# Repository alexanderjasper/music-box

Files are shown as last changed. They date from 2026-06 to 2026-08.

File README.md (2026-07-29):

# Music Box

A phone-free way to control our Sonos speakers at home.

Place a physical card on the device, press play, and a corresponding album,
playlist, or radio station starts playing on one or more speakers. No screen to
get lost in, no app to open — just a tactile object and a button.

> **Status:** Scoping / idea phase. This README is a living design document.
> Nothing is built yet. Decisions marked **(open)** are still to be made.

---

## Motivation

When I'm home, I want to fully put my phone away. Today, playing music on our
3 Sonos speakers requires picking music or a radio station through the Sonos
app on my phone every single time. That pulls the phone back into my hand — and
my attention with it.

The Music Box replaces that with a physical, ambient interaction:

- Pick a card (album / playlist / radio station / mood).
- Place it on the box.
- Press play.
- Music plays on the speaker(s).

The phone stays away.

---

## Core concept

```
   [ physical card ]                  [ Sonos speakers ]
          │                                   ▲
          ▼                                   │
   ┌──────────────┐     local network /       │
   │  Music Box   │ ───── UPnP / API ─────────┘
   │  (no display)│
   │  buttons +   │
   │  card reader │
   └──────────────┘
          ▲
          │ configuration over Wi-Fi / Bluetooth
          │ (map card → music, no display needed on device)
   [ phone / laptop, only for setup ]
```

The phone is still allowed for **one-time configuration** (mapping a card to a
playlist). The goal is zero phone use for **everyday playback**.

---

## Goals

- **No general-purpose display.** Buttons only. Optionally a minimal display for
  track progress / time elapsed / volume — nothing you'd "browse".
- **Tactile cards** to select what plays.
- **One or more speakers** targetable per action (grouping).
- **Configuration off-device** — over local network and/or Bluetooth, from a
  phone or laptop.
- **Built from off-the-shelf electronics + 3D-printed enclosure** (Prusa Core One).
- Reliable and fast enough that it actually replaces the app for daily use.

## Non-goals (for now)

- Not trying to replicate the full Sonos app.
- No on-device music browsing/search.
- No cloud service of our own — keep everything local where possible.

---

## Open questions to scope together

These are the big decisions. We'll work through them and record the outcomes here.

### 1. Card technology **(DECIDED: NFC)**
**NFC tags** — an NTAG215 sticker hidden inside each 3D-printed card, read by a
PN532/RC522 reader in the box. Cheap (~€0.20/card), batteryless, scales to 100s,
solder-free modules exist. The card just rests on a marked "spot." Each tag's UID
(or a written ID) maps to a Sonos Favorite in the box config.

### 2. The "brain" **(leaning Raspberry Pi — see findings)**
What runs the logic and talks to Sonos?
- **Raspberry Pi Zero 2 W** — runs Linux + Python, uses [SoCo] directly, hosts the
  config web app easily. The findings make this the strong default: SoCo is the
  proven, maintained path and needs a real OS. Boots slower / more power than an MCU,
  but for an always-on box that's fine.
- **ESP32** — cheap, instant-on, but would need raw UPnP reimplemented (no SoCo) and
  the config web app is more work. Findings push this *down* the list.
- Other (Pi 4/5, etc.) — overkill but flexible.

[SoCo]: https://github.com/SoCo/SoCo

### 3. How we talk to Sonos **(open)**
- **Local UPnP control** (SoCo) — no internet dependency, works on the LAN.
- Sonos **favorites** as the unit of selection — easiest mapping target: a card
  → a Sonos favorite (which can be an album, playlist, or radio station).
- Music sources we care about (**decided**, see findings below): **Apple Music**,
  **DR radio + DR podcasts** (via the **DR LYD** Sonos service). Other services
  can be added later. Podcasts beyond DR are a known gap — see findings.

### 4. Buttons & controls **(DECIDED — see "Control scheme" below)**
Settled on, per room: a **latching push-button** (arm/disarm, room label on the cap,
stays pressed in when armed — no LED) **and** a separate **volume knob** (rotary
encoder). Plus **shuffle** + **repeat** latching symbol buttons, **previous / play /
next** momentary buttons, and a **piezo buzzer** for audio feedback. No LEDs anywhere
on the box. No dedicated mute (disarm a room, or turn its knob to zero).

### 5. Display: none vs. minimal **(open)**
- None at all.
- Minimal: small OLED / e-ink showing track name + elapsed/remaining time +
  volume. Nice-to-have, not required for v1.

### 6. Configuration interface **(DECIDED: LAN web app with live card enrollment)**
A small **web app served by the box** on the LAN, opened from any phone/laptop. On the
finished Pi this is reachable at **`musicbox.local`** (Raspberry Pi OS ships Avahi/mDNS,
so setting the Pi's hostname to `musicbox` makes `<hostname>.local` resolve with no DNS
setup; the bare name needs the app on port 80, otherwise it's `musicbox.local:8080`). On
the **dev machine today** it's `http://localhost:8080` (and `http://<LAN-IP>:8080` from a
phone) — the simulator doesn't advertise the `musicbox` name. It lists your **Sonos
Favorites live** (via SoCo) and lets you bind a card
by simply **placing it on the box's own NFC spot** — the PN532 reads the UID and the page
captures it. See "Card configuration" below for the full flow. No Bluetooth flow for v1.

### 7. Card ↔ action model **(DECIDED: card = a named Sonos Favorite, content only)**
A card stores **just the favorite** (its NFC UID → favorite name in the box config).
**Rooms and volume are chosen live** with the panel buttons/knobs each time, not baked
into the card — so cards stay interchangeable. (Considered and deferred: "scene" cards
that also remember rooms/mode/volume. The data model leaves room to add optional defaults
later without breaking existing cards.)

### 8. Power & resilience **(DECIDED: wall power for v1; read-only root FS; battery deferred — two options documented)**

**v1 is wall-powered** — a **5V micro-USB PSU (≥2.5A)** (the Pi Zero takes micro-USB, *not*
USB-C). For an always-on box that drives Sonos, mains is the simplest, most reliable choice
and a battery buys nothing for everyday use.

**Read-only root filesystem — decided regardless of power source.** The box runs with
Raspberry Pi OS's **overlay filesystem** (`raspi-config` → Performance → Overlay FS): root
mounts read-only with a RAM overlay, so **any power cut — yanked cable, home outage, or a
drained battery — can never catch the SD card mid-write.** This removes the real risk of
ungraceful shutdown, which is *not* our app's data (just `cards.json`, written rarely during
enrollment) but **OS/SD corruption** from background writes + the SD card's own wear-levelling
— a risk independent of how little we write. `cards.json` lives on a small writable partition
and is saved **atomically** (temp file → `fsync` → rename), so a yank yields either the old or
new file, never a torn one. This hardens the *wall-powered* box too (outages, "unplug = done").

**Battery is deferred — an optional "portability" mode, not in v1.** v1 ships wall-powered;
the goal *if* battery is added later is to actually carry the box between rooms / outside. Two
options are documented (full parts in the BOM "Battery / portability" section); pick when/if
the time comes. Either way the **read-only root FS** above means a flat pack or yanked cable
can't corrupt the SD card.

- **Option A — rechargeable AA (NiMH).** No lithium in a printed case, cells **hot-swap** (keep
  a charged spare set), core parts all at BerryBase. **4× AA + a 5V buck-boost** → the Pi's 5V;
  ~4× 2000mAh ≈ 9.6Wh → roughly **8 h** at the box's ~1W draw. Trade-offs: recharge by *swapping*
  cells (NiMH needs an external charger — no charge-in-place), and no fuel gauge → **no
  auto-shutdown**, replaced by a **low-battery buzzer cue** ("swap soon"). For **seamless**
  wall↔battery hand-over (no reboot) add an **auto-switching power mux (TPS2113A)** between the
  two 5V sources; without it, swapping reboots the Pi — harmless under read-only root, just not
  gapless. (Note: 4 fresh NiMH ≈ 5.2–5.4V, *above* 5V, so it must be a buck-**boost**, not a
  plain step-up.)
- **Option B — LiPo + PiSugar 3.** A clip-on UPS board (pogo pins to the Pi's back — *doesn't*
  use the 40-pin header) with charge-in-place over USB, an **I²C fuel gauge**, RTC, and seamless
  switchover built in. Cheapest route to gapless hot-swap (~€45–55 landed). Trade-offs: a
  **lithium cell inside the enclosure**, the stock cell is 1200mAh (~3 h, swappable for a bigger
  one), and it ships from outside the EU (not BerryBase).

**Software implications (either option):** the atomic `cards.json` save (above) and a distinct
**low-battery buzzer cue** in the existing cue vocabulary. Auto-shutdown is *nice-to-have* —
trivial with PiSugar's I²C gauge, skipped on AA (read-only root makes it non-essential).

---

## Technical findings: Sonos & Bluetooth (researched 2026-06-06)

A research pass into how the box can actually drive speakers. Sources are linked
at the bottom of this section.

### Two fundamentally different speaker models

This is the single most important realization, and it shapes the whole project:

- **Sonos = the box is a _controller_.** Sonos speakers are networked players that
  stream music *themselves* (directly from Apple Music's / DR's servers over your
  Wi-Fi). The box only sends commands like "play favorite X on the kitchen
  speaker." The box never touches the audio. This is lightweight, reliable, and
  a great fit for a small always-on device.
- **Bluetooth speaker = the box is the _audio source_.** A plain Bluetooth speaker
  has no idea what Apple Music is. The box itself would have to fetch, decode, and
  stream the audio over Bluetooth. That's a much heavier job — **and there is no
  good way to play Apple Music from a headless Linux device** (no official API /
  client). So **Bluetooth + Apple Music is effectively a dead end.** Bluetooth
  could work for *local files, internet radio, and podcast RSS streams*, but not
  our main source.

**Implication:** scope **v1 to Sonos only** (controller model). Bluetooth output
can be a *later, separate mode* limited to radio/podcasts/local files — not a
drop-in for Apple Music. ([Phoniebox] does BT this way, with local/Spotify audio.)

### How the box talks to Sonos

- **Local control via [SoCo]** (Python, UPnP over the LAN) is the recommended path.
  It is **actively maintained in 2026**, works on current Sonos S2 devices, and
  needs **no cloud account and no internet** for the control commands themselves.
- Sonos also has an **official cloud Control API**, but it requires OAuth + their
  cloud and has been less reliable (and the `getFavorites` cloud endpoint is
  reported as buggy). For an always-on local box, **local SoCo is the better bet.**
- SoCo handles the things we need: play/pause, next/prev, volume, **speaker
  grouping** (one or more speakers per action), and **listing/playing Sonos
  Favorites**.

### The Apple Music catch — and the workaround

- Apple Music on Sonos is an **account-linked service** using Sonos's SMAPI. Starting
  Apple Music playback *directly* by URI through SoCo / the API is **unreliable**
  (Apple Music, Spotify, Amazon are all flagged with auth/playback issues).
- **The robust pattern: Sonos Favorites.** You add the albums/playlists/stations you
  want to **My Sonos → Favorites** *once* in the Sonos app. The box then lists those
  favorites via SoCo and plays them by name. This sidesteps the broken
  direct-playback path and works across services.
- **Consequence for the card model:** each card maps to a **named Sonos Favorite**
  (+ a target speaker/group). Setup flow = "add it to Sonos Favorites, then assign a
  card to it" in our config web app. This scales fine to **100s of cards**.

### DR radio & podcasts — good news

- **DR LYD is a first-class Sonos music service** (Danish). It carries DR's **live
  radio channels, on-demand shows, _and_ podcasts**. So DR radio *and* DR podcasts
  are both reachable — save them as Sonos Favorites like anything else.
- **Podcasts outside DR — solvable, and even feasible in v1.** Apple **Podcasts** is
  *not* a Sonos service, but a podcast is just an **RSS feed whose episodes are plain
  HTTP audio URLs**. So the box can fetch the feed, pick the latest/next episode, and
  hand its `.mp3`/`.aac` URL to Sonos via `play_uri()` — the speaker streams it itself.
  A card → "the RSS URL for *Podcast X*". Open design bits: "latest vs. resume" per
  card, and remembering playback position. Not a blocker.

### Can the box play audio over Bluetooth later? (Pi Zero 2 W)

- **Yes — the Pi Zero 2 W is powerful enough.** Built-in Bluetooth + quad-core CPU can
  decode MP3/AAC/FLAC and stream to a BT speaker as an **A2DP source** (`bluez` +
  `bluealsa`). [Phoniebox] does exactly this on Pi-Zero-class hardware.
- **The limit is licensing, not CPU.** Local files, internet radio, and podcast RSS
  audio can all go out over Bluetooth. **Apple Music cannot** (no headless Linux
  client) — so BT output would be a radio/podcasts/local-files mode, never Apple Music.
- Net: choosing the Pi Zero 2 W keeps the future Bluetooth-output option open with no
  regret.

### Prior art worth studying

- **[Phoniebox] (RPi-Jukebox-RFID)** — mature Raspberry Pi + RFID jukebox; plug-and-play
  over USB, *no soldering required*, supports web radio/podcasts/Spotify and BT output.
  Great reference for the RFID + config-web-app + assembly approach, even though it
  targets local/Spotify rather than Sonos.
- **[zacharycohn/jukebox]** — a Raspberry Pi + NFC + **SoCo** Sonos jukebox. Closest to
  our concept; maps NFC tags → playlists. Confirms the SoCo approach works.

[SoCo]: https://github.com/SoCo/SoCo
[Phoniebox]: https://github.com/MiczFlor/RPi-Jukebox-RFID
[zacharycohn/jukebox]: https://github.com/zacharycohn/jukebox

---

## Control scheme (decided 2026-06-06)

No general-purpose display. State is shown by the physical controls themselves
(a toggle's position, an encoder's LED) rather than a screen.

```
            ┌──────────────────────────────────────┐
            │   ·  place card here  ·               │   <- NFC "spot"
            │                                       │
            │  [Alrum][Køkken][Grys][ - ][ - ]      │   <- 5 room buttons (label on cap; pressed in when armed)
            │   (O)    (O)    (O)   (O)  (O)         │   <- 5 room volume knobs (turn only)
            │   [⤬]        [↻]                       │   <- shuffle / repeat symbol buttons
            │                                       │
            │   (<<)   ( PLAY )   (>>)               │   <- previous · play/pause · next
            └──────────────────────────────────────┘
                                                      ((•)) piezo buzzer (audio feedback)
```

The box has **5 room slots** even though we run 3 Sonos speakers today — the two
spare button/knob pairs sit unlabelled until you add more speakers, then you just
label the cap and map the button to the new room in config. (Five was chosen for
future-proofing; the Pi's GPIO comfortably fits it — see the BOM's pin budget.)

- **Per room (5 slots; Alrum / Køkken / Grys værelse + 2 spare): a press button + a
  volume knob, as two separate controls.**
  - **Room button** = arm/disarm that room. The room's own label is on the cap
    (printed or hand-applied — the box ships unlabelled). It is a **latching push-button
    (push-on/push-off)** — the cap **stays pressed in when armed**, so its physical
    position shows state with **no LED**. (It also holds across power-off, so the box
    remembers your room selection — the Pi just reads the switches at boot.)
  - **Volume knob** = that room's volume. A **rotary encoder** (relative, "turn up/down")
    rather than a potentiometer, because the Pi has no analog input — an encoder reads
    cleanly over GPIO. Maps to SoCo per-room volume.
  - (Design evolved 2026-06-06: combined push-encoder → separate switch → finally an
    illuminated press button with the label on the cap, per preference.)
- **Play** button: group the currently-armed rooms (SoCo `join`/`unjoin`) and play
  the favorite mapped to the card sitting on the spot. Press again = pause/resume.
  It carries a **single fixed play/pause symbol** (a molded button can't change its
  face) — playback state is shown by the button's LED, not by swapping the glyph.
  - **If no room is armed, `play` does nothing** except sound a short **error beep**
    (see buzzer below). No silent no-op, no surprise default room.
- **Removing the card stops playback.** Lifting the card off the spot is the natural
  "stop" — like taking a record off a turntable. (Pause/resume stays on the play button.)
- **Previous / Next** buttons: skip within the current queue (SoCo `previous()` /
  `next()`). Some favorites are single tracks where skip won't apply — that's fine.
- **Shuffle** and **Repeat** latching symbol buttons: push-on/push-off; the symbol is
  raised in a contrasting colour (a multi-material print) and the cap **stays pressed
  in when active**. Map to SoCo `play_mode` (NORMAL / SHUFFLE / REPEAT_ALL / SHUFFLE_NOREPEAT).
- **Piezo buzzer (audio feedback):** a small piezo on a GPIO pin gives a screenless
  device a voice. Yes, the Pi does this easily — a passive piezo + PWM can play tones,
  an active one just beeps; it does **not** use the (absent) audio jack. Planned cues:
  - card recognized → short rising chirp
  - room armed / disarmed → soft click (arm) / lower click (disarm)
  - play started → confirmation blip
  - **error (e.g. play with no room armed, or unknown card) → low error buzz**
- **Optional minimal display (later):** small OLED for track + elapsed/remaining
  time + a volume blip. Nice-to-have, not v1.
- **Mute:** no dedicated control — the existing controls cover both intents.
  Flip a room's switch off (`unjoin`, stops it) or turn its knob to zero (stays grouped, silent).
- **Still open:** whether arming a room while audio is already playing should hand it
  the current track immediately or wait for the next play.

---

## Card configuration (decided 2026-06-06)

How you assign a physical card to music **after the box is built** — using only the
hardware already in the box (no extra reader, no writing to the tags).

**Config file** — the box keeps a map keyed by each tag's factory **NFC UID**:

```jsonc
{
  "04A2B3C4D5E6": { "favorite": "Bohemian Rhapsody" },
  "04F1029384AB": { "favorite": "DR P6 Beat" }
}
```

The name written/printed on the card is purely for humans; the box matches on UID.
(Today's `software/cards.json` is keyed by the written name as a stand-in — same shape;
the UID replaces the key on real hardware.)

**Enrollment flow** (the web simulator we built grows into this):

1. Open the box's web app from a phone/laptop on the same Wi-Fi — **`musicbox.local`**
   on the finished Pi (see config-interface note above), or `http://localhost:8080`
   against today's simulator.
2. The page lists your **Sonos Favorites live** (via SoCo) — albums, playlists, DR LYD
   stations/podcasts you've saved in the Sonos app.
3. **Place the card on the box's NFC spot.** The PN532 reads its UID; the page shows
   *"new card detected"* (or, if already mapped, its current favorite).
4. **Pick a favorite → Save.** Write the name on the card, drop it in the deck.

**Disambiguation** — placing a card normally **plays** it; the box only treats a tap as
*enrollment* while the config page's "Add card" mode is active. No mode switch or extra
button on the box itself. Re-assigning a card = place it, the page shows its current
mapping, change it. Bulk enrollment is just tapping through the stack a few seconds each
(fine for 100s, since each card is a unique object anyway).

## Likely architecture (first hypothesis, to be challenged)

> This is a starting point, **not** a committed decision.

- **Raspberry Pi Zero 2 W** running Python.
- **PN532 NFC reader** over SPI/I²C; cards are 3D-printed holders with an NFC
  sticker inside.
- **[SoCo](https://github.com/SoCo/SoCo)** for local Sonos control; each card maps
  to a **named Sonos Favorite** + target speaker/group (see findings above for why
  Favorites, not direct Apple Music URIs).
- A few **momentary push buttons** (play/pause, vol ±, next).
- Optional **small OLED** for track + time.
- A **local web app** (served from the Pi) for configuration: scan a card, pick
  the favorite + target speakers, save.
- **USB-C** powered.
- **3D-printed enclosure** with a card "slot" or "tray" and recessed buttons.

---

## Hardware (to be finalized)

| Part | Candidate | Notes |
|---|---|---|
| Compute | Raspberry Pi Zero **WH** (or Zero 2 WH) | Needs an OS for SoCo + web config. Original Zero W is fine for Sonos-only; Zero 2's quad-core only matters if the Pi later plays Bluetooth audio itself. Swappable later. |
| Card reader | PN532 (I²C/SPI) | NFC; PN532 preferred over RC522 for interface flexibility |
| Cards | NTAG215 stickers in printed holders | Cheap, batteryless, 100s scale |
| Room arm | 5× latching push-button | One per room slot (3 used + 2 spare); label on cap; stays pressed in when armed (no LED) |
| Room volume | 5× rotary encoder | One per room slot; relative (no ADC needed on the Pi) |
| Mode buttons | 2× latching push-button | Shuffle, repeat symbols; stay pressed in when active |
| Transport | 3× momentary button | Previous, play/pause, next |
| Audio feedback | 1× piezo buzzer (GPIO) | Chirps/clicks/error beep; no audio jack needed |
| Display | SSD1306 OLED (optional, later) | Track + time only |
| Power | 5V micro-USB PSU (≥2.5A) | Pi Zero uses micro-USB, not USB-C |
| Enclosure | 3D printed (Prusa Core One) | Card spot + encoders + buttons |

See **[`hardware/BOM.md`](hardware/BOM.md)** for the full shopping list with quantities,
Danish/EU retailers, indicative prices, and the Pi GPIO pin budget.

## Software so far

All control logic lives in `software/musicbox/` (the `MusicBox` core) with **no UI
or hardware dependency**. Three thin front-ends drive the same brain: the CLI, the
web simulator, and — now — the **real GPIO panel on the Pi**.

- **`software/spike_sonos.py`** — the original de-risking spike (discover / list
  favorites / play one). ✅ validated against the real speakers.
- **`software/spike_gpio.py`** — first on-Pi hardware bring-up (button → buzzer).
- **`software/musicbox/`** — the core (room arming/grouping, per-room volume, play
  modes, transport, card→favorite playback, the buzzer cue vocabulary), plus:
  - **`musicbox/hardware/`** — the **config-driven hardware layer**: a `Panel` reads
    `hardware.json` and builds *only* the controls you've actually wired (room
    buttons, volume encoders, the PN532 reader, the piezo), wiring them to the core
    via the slot→room map. **Adding a part is a JSON edit, not a code change.**
  - **`musicbox/service.py`** — the on-device service: the panel **and** the config
    web app over one shared box. `software/musicbox.service` is the systemd unit
    that runs it at boot.
- **CLI simulator** — `python -m musicbox`, simulates the panel via typed commands.
- **Web app** — `python -m web.server`: the config app at `/` — map room slots →
  Sonos rooms, bind NFC tags → **Sonos favorites or Sonos playlists** (with live
  place-a-card enrollment), and print card labels at `/labels`. On the device this
  is served at `musicbox.local`.
- **Config files** in `software/` (copy from each `*.example.json`): `hardware.json`
  (which controls exist + their pins — hand-edited as you wire), `rooms.json`
  (slot → Sonos room) and `cards.json` (tag UID → favorite). The last two are written
  by the web app **atomically** (see open question #8).
- **`software/tests/`** — logic tests with fake speakers, no Sonos/GPIO needed
  (`core`, `config`, `panel`, `web`); run each with `python tests/<name>.py`.

Run the simulator on a laptop:

```
cd software
python3 -m venv .venv && source .venv/bin/activate
pip install -r requirements.txt
python -m web.server          # faceplate at :8080/ , setup at :8080/config
```

Run on the Pi (real controls + config app together):

```
cd software
sudo apt install -y python3-gpiozero python3-lgpio
pip install --break-system-packages -r requirements-pi.txt
cp hardware.example.json hardware.json     # then edit to match your wiring
python -m musicbox.service                 # then open http://musicbox.local
```

Then start it at boot, so the box works when you just plug it in:

```
sudo cp musicbox.service /etc/systemd/system/    # check User= and WorkingDirectory=
sudo systemctl enable --now musicbox
journalctl -u musicbox -f                        # follow the log
```

It waits for the network (SoCo discovers Sonos at startup) and restarts on crash.
When you switch the root filesystem to read-only (open question #8), set
`MUSICBOX_DATA_DIR` in the unit to a writable mount — otherwise the cards and rooms
the web app saves land in the RAM overlay and disappear on the next reboot.

To push code updates from your laptop afterwards, use `software/sync.sh`. It
rsyncs everything **except** the device's own runtime config (`cards.json`,
`rooms.json`, `hardware.json`) — the files the web app writes on the box — so a
deploy never wipes your enrolled NFC cards or room mapping:

```
cd software
./sync.sh                       # -> alexander@musicbox.local:~/software/
./sync.sh pi@192.168.1.42       # or a different host
```

### Printing the card labels

The cards take 60 x 60 mm die-cut labels (etiketlageret A4-12, 12 per sheet). The
box serves a page for it at **`musicbox.local/labels`**: pick a Sonos
favourite per label and its cover art is fetched from the speakers, or drop in your
own picture when a cover is too low-res. Press *Make the sheet* and it opens as a
PDF to print. Only the labels you choose are filled, so a part-used sheet can be
finished off later.

There is a command-line equivalent for the same job:

```
cd tools
./labels.py sheet.pdf 5=cover.jpg 6=other.png    # slots 1..12, L-R, top-bottom
./labels.py grid.pdf --calib                     # outlines + numbers, plain paper
```

Sheet geometry and PDF writing live in `software/web/labelsheet.py`, shared by
both. Images are embedded as JPEG (no PDF library needed) and scaled with Pillow
where it is installed, falling back to macOS's built-in `sips`.

Print **at 100%** — any "fit to page" and the alignment is gone. Images are
centre-cropped square and overshoot each label by 1 mm so a slightly off die-cut
still prints edge to edge (`--bleed 0` for exact size); 470 px or more keeps it
above 200 ppi.

The grid is taken from the vendor's own template (60 x 60 labels, 5 mm gutters,
10 mm from the left, 20 mm from the top of an A4 page), verified by rendering
both that template and our output at 1 px/mm and comparing the die-cut lines. If
your printer still shifts the page, `--dx/--dy` nudge everything.

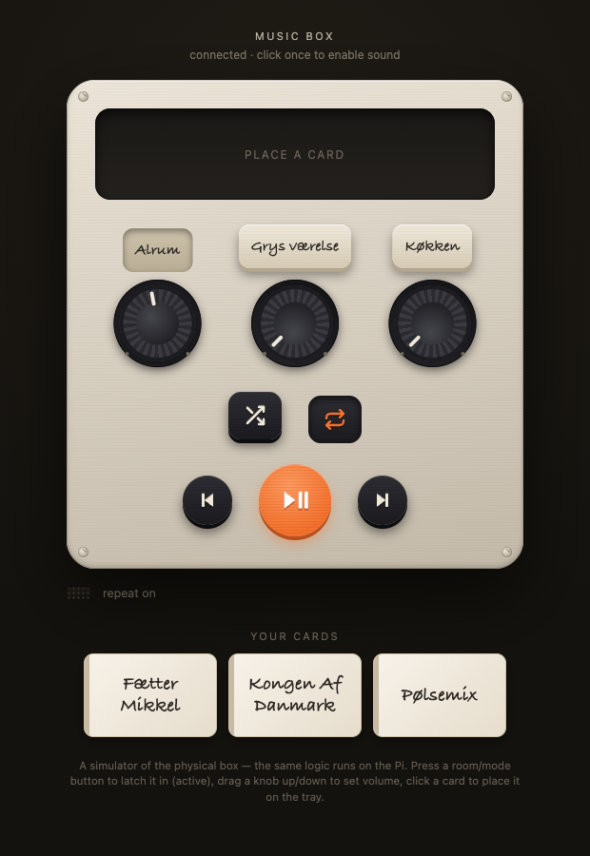
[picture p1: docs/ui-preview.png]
Web simulator faceplate


*The web simulator: warm 3D-printed-style enclosure, illuminated per-room arm buttons
(label on the cap) + volume knobs (level shown by pointer rotation, no display),
3D-printed shuffle/repeat symbol buttons, prev/play/next, a card tray, and your deck of
handwritten cards. Drives the real Sonos.*

## Repository layout

```
/software                # the code (musicbox core, CLI, web simulator, tests)
/hardware                # wiring diagrams, BOM, pinouts
/cad                     # OpenSCAD models for the enclosure (single-speaker v1) and cards
/docs                    # design notes, decisions, the UI preview
```

---

## Roadmap (rough)

1. **Decide the open questions above** (this phase).
2. **Spike**: get Python + SoCo controlling our actual Sonos speakers from a
   laptop — prove playback control end to end.
3. **Spike**: read an NFC card ID on the chosen brain.
4. Wire card → Sonos favorite → playback (breadboard, no enclosure).
5. Add buttons.
6. Build the config web app.
7. Design + print the enclosure and cards.
8. Assemble, polish, live with it, iterate.

---

## Notes / decisions log

### 2026-06-07 — Power: wall for v1, read-only root FS, battery deferred (two options documented)
Scoped open question #8. **v1 ships wall-powered** (5V micro-USB ≥2.5A) — first build orders no
battery. Adopted a **read-only root filesystem** (Raspberry Pi OS overlay FS) so power loss can't
corrupt the SD card — the real ungraceful-shutdown risk is OS/SD corruption, not our tiny
`cards.json` (now saved atomically). This hardens the wall build *and* de-risks any future
battery. Battery is left as an optional **portability** mode with **two documented paths**, to
choose later: **(A) rechargeable AA (NiMH)** — 4× AA + 5V buck-boost, no lithium in the case,
hot-swap cells, ~8 h, BerryBase parts; recharge by swapping (external charger), no fuel gauge →
low-battery buzzer cue instead of auto-shutdown; seamless wall↔battery hand-over needs an added
TPS2113A power mux (not at BerryBase). **(B) LiPo + PiSugar 3** — clip-on UPS, charge-in-place,
I²C gauge, seamless built in, ~€45–55 landed; downside is a lithium cell in the enclosure and
~3 h on the stock 1200mAh. See BOM "Battery / portability".

### 2026-06-06 — Pi board: original Zero W accepted (Sonos-only); BerryBase sourcing
The Zero 2 W was hard to find in stock, so we accepted the **original Pi Zero WH**
(single-core, header pre-soldered) for v1 — its CPU is plenty for the **Sonos-controller**
workload (SoCo sends commands; the speakers stream). The quad-core Zero 2 only matters for
the deferred "Pi plays Bluetooth audio itself" idea, and the board is **swappable later**
(identical 40-pin header, SD card moves over) so it's no lock-in. Sourcing consolidated to
**[BerryBase.de](https://www.berrybase.de/en/)** as a single EU order (ships to DK, no
customs); see [`hardware/BOM.md`](hardware/BOM.md). Watch-outs captured there: PSU must be
**≥2.5 A** (not 1 A), buttons must be **latching/rastend** (not momentary), piezo must be
**passive**, and use the PN532 **module** (not the HAT, which would occupy our GPIO header).

### 2026-06-06 — Card configuration: UID-keyed, enrolled on the box itself
Cards are configured via the **box's own LAN web app**: it lists Sonos Favorites live,
and you bind a card by **placing it on the box's NFC spot** (the PN532 reads the factory
UID — nothing is written to the tag). Config is a `UID → favorite` map. A card stores
**only the favorite** (content); **rooms and volume stay live** on the panel, so cards
are interchangeable. Considered "scene" cards (card remembers rooms/mode/volume) and
deferred — the schema can gain optional defaults later without breaking existing cards.

### 2026-06-06 — Five room slots (future-proofing)
The panel is built for **5 rooms**, not the 3 speakers we own today, so adding speakers
later needs no rebuild — just label a spare cap and map its button to the new room in
config. Kept **one volume knob per room** (5 knobs), consistent with the existing design.
GPIO fits comfortably: **23 of 26 pins** used (PN532 ×2, 5 encoders ×2, 5 room + 2 mode
buttons, 3 transport, 1 piezo). The `MusicBox` core already discovers speakers
dynamically, so software needed no change; this is a hardware/layout + BOM decision.

### 2026-06-06 — Latching push-buttons, no LEDs anywhere
Room arm and shuffle/repeat are **latching push-buttons** (push-on/push-off): the cap
**stays pressed in when active**, so the physical position shows state — **no LEDs on
the box at all**. They also hold across power-off, so the box remembers your room
selection (the Pi reads the switch positions at boot). Transport stays momentary; the
play/pause button shows no state (you hear the music). This replaced the illuminated-
button idea below.

### 2026-06-06 — Controls are illuminated press buttons; labels on the caps
Final control form (after the simulator made it tangible): room arm and shuffle/repeat
are **illuminated push-buttons**, not flip switches. The **room's label lives on the
button cap** (printed/hand-applied; the box itself is unlabelled), and an LED shows
armed/active state. Shuffle/repeat carry their **symbol raised in a contrasting colour**
(multi-material print). Volume stays a separate rotary-encoder knob per room, showing
level by pointer rotation — no numeric display anywhere on the box.

### 2026-06-06 — Control revision: separate arm switch from volume knob
Superseded the "one push-rotary encoder does both" idea. Per room there are now
**two** controls: a **latching toggle switch** to arm/disarm (position shows state)
and a **separate volume knob** (rotary encoder). Reason: each control does one
obvious thing, and arming is visibly indicated without relying on a hidden "push the
knob" gesture. Costs a few more panel holes; worth it for clarity.

### 2026-06-06 — Sonos spike VALIDATED ✅
Ran `software/spike_sonos.py` against the real speakers. All three commands
worked first try:
- **Discovery** found 3 speakers: `Alrum`, `Grys værelse`, `Køkken`.
- **Favorites** listed 17 Sonos Favorites (mix of Apple Music tracks, DR /
  Sonos Radio, kids' content).
- **Play** started an **Apple Music** favorite ("Bohemian Rhapsody") on `Køkken`.

**Conclusion:** the core control assumption holds. Apple Music playback via
Sonos Favorites + local SoCo works end to end. Biggest project risk is retired.

Follow-up note: today's favorites are mostly individual *tracks*. For the real
device we'll want to also save *albums / playlists / radio stations* as
Favorites in the Sonos app — they work the same way, just longer-playing.

### 2026-06-06
- **Music sources for v1:** Apple Music, DR radio, DR podcasts (DR radio + podcasts
  both via the DR LYD Sonos service). Other services later.
- **Card count:** must scale to **100s** of cards.
- **Builder skill:** new to soldering/breadboarding but keen to learn → favor
  solder-free / plug-together modules where possible (e.g. Phoniebox-style).
- **Speaker target for v1:** **Sonos only** (controller model). Bluetooth output
  deferred to a possible later mode, and noted as **incompatible with Apple Music**.
- **Sonos control method:** local **SoCo** (UPnP, no cloud) is the chosen approach.
- **Card → action model:** each card = a **named Sonos Favorite** + target speaker/group.
  Pre-add content to Sonos Favorites once, then assign cards to favorites in config.
- **Brain:** leaning **Raspberry Pi Zero 2 W** (needed for SoCo + web config).
- **Known limitation:** non-DR podcasts (e.g. Apple Podcasts) aren't a Sonos service;
  reachable later via RSS → direct audio URL, out of scope for v1's first cut.
- **Card tech:** **NFC** (NTAG215 in printed cards + PN532 reader). See open question 1.
- **Controls:** **one push-rotary encoder per room** (push = arm/disarm, turn = volume),
  **shuffle** + **repeat** toggle switches, **previous / play / next** buttons. No
  screen; control positions/LEDs show state. Volume is per-room via the knobs.
- **Play with no room armed:** do nothing except sound an **error beep**.
- **Audio feedback:** add a **piezo buzzer** on a GPIO pin for card-recognized chirps,
  arm/disarm clicks, play confirmation, and error beeps. Confirmed the Pi can drive
  this directly (PWM tones / active beep) without using an audio output.

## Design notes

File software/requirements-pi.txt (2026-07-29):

# Raspberry Pi-only dependencies — install on the device with the system Python
# (where the GPIO/I²C backends live), NOT in the laptop venv:
#
#     sudo apt install -y python3-gpiozero python3-lgpio
#     pip install --break-system-packages -r requirements-pi.txt
#
# The laptop simulator only needs the top-level requirements.txt (soco + flask).

soco>=0.30                          # the box drives Sonos directly
flask>=3.0                          # the box also serves the config web UI
gpiozero>=2.0                       # buttons, rotary encoders, the buzzer
lgpio>=0.2                          # gpiozero's pin backend on Raspberry Pi OS Bookworm
adafruit-circuitpython-pn532>=2.4   # PN532 NFC reader over I²C
adafruit-blinka>=8.0                # CircuitPython compatibility layer (board/busio)
pillow>=10.0                        # scales album art for the label sheets
                                    #   apt install python3-pil is fine too

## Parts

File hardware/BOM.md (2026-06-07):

# Bill of Materials & where to buy

Everything needed to build the Music Box. You already have the **3D printer + filament**,
so all knobs, button caps and the enclosure are printed (free). Prices are indicative
(incl. VAT) and will vary — check current listings. Quantities are for the agreed design:
**up to 5 rooms** (3 speakers today + 2 spare slots for future expansion), NFC cards, no
display.

> **Recommended: one order from [BerryBase.de](https://www.berrybase.de/en/).** It stocks
> essentially every part below, cheaply, and ships from Germany to Denmark with **no
> customs** (EU). A single BerryBase order covers the whole electronics build (specific SKUs chosen for the
> controls — see items 6–8) for roughly **€55–75**. The **Buy** column lists BerryBase
> first, with Danish shops as alternates if something's out of stock. One pick still
> needs care — see the ⚠️ flag on the PN532 (get the **module**, not the HAT, which would
> occupy our GPIO header).

> New to soldering? The **WH** board has its 40-pin header pre-soldered, so the Pi needs
> none. Encoders, buttons, the buzzer and the NFC module still need a few solder joints
> for the final build — but start on a **breadboard** first (no soldering) to prove the
> wiring.

## Core electronics

| # | Part | Qty | ≈ price | Buy (BerryBase first, DK alt.) | Notes |
|---|---|-----|---|-----|---|
| 1 | **Raspberry Pi Zero WH** (or **Zero 2 WH**) — pre-soldered header | 1 | €18–25 | [BerryBase Zero WH](https://www.berrybase.de/en/raspberry-pi-zero-wh) · [raspberrypi.dk (2 WH)](https://raspberrypi.dk/en/product/raspberry-pi-zero-2-wh-with-presoldered-header/) | The brain. **WH** = no header soldering. Original **Zero W is fine for Sonos-only**; the quad-core **Zero 2** is only worth chasing if you later want the Pi to play Bluetooth audio itself. The Pi is swappable later (same header, SD card moves over). |
| 2 | microSD card **16 GB, A1** (32 GB fine) | 1 | €7–16 | [BerryBase Pi memory cards](https://www.berrybase.de/en/raspberry-pi/raspberry-pi-computer/memory-cards/) · [SanDisk Ultra 32GB (€15.60)](https://www.berrybase.de/en/sandisk-ultra-microsdhc-a1-120mb/s-class-10-speicherkarte-adapter-32gb) | Runs Raspberry Pi OS Lite (~4 GB), so **16 GB is plenty** — 32 GB is overkill. Must be **A1** (random-I/O = a responsive Pi); genuine SanDisk only (fakes corrupt on boot). Reuse any ≥8 GB A1 card you own to save the cost. |
| 3 | **5V micro-USB PSU, 2.5A** | 1 | €8–12 | [BerryBase Pi micro-USB PSU 5V/2.5A](https://www.berrybase.de/micro-usb-netzteil-fuer-raspberry-pi-5v/2-5a-schwarz) | Pi Zero uses **micro-USB** (not USB-C). This one is **2.5 A** — don't substitute a 1 A adapter (browns out under Wi-Fi). |
| 4 | **PN532 NFC module** (I²C/SPI/UART) ⚠️ | 1 | €7–12 | [BerryBase module (+card+dongle)](https://www.berrybase.de/en/pn532-nfc-und-rfid-modul-inkl.-karte-dongle) · [bitbyg](https://bitbyg.dk/shop/pn532-nfc-rfid-module-v3/) · [arduinotech](https://arduinotech.dk/nfc-pn532-modul-brik/) | Reads the cards over I²C (2 wires + power). ⚠️ Get the **module**, *not* the [PN532 HAT](https://www.berrybase.de/en/pn532-nfc-hat-for-raspberry-pi-i2c-spi-uart) — the HAT occupies the 40-pin header we need for buttons/encoders. |
| 5 | **NTAG215 NFC tags** (25 mm, self-adhesive) | 5–10 packs of 10 | €3–5 /pack | [BerryBase (self-adhesive ×10)](https://www.berrybase.de/en/rfid-nfc-tags-ntag215-25mm-self-adhesive-white-10-pieces) · [plain ×10](https://www.berrybase.de/en/rfid-nfc-tags-ntag215-25mm-white-10-pieces) · [idekort (bulk)](https://idekort.dk/vare-kategori/rfid-og-kontaktloese-kort-og-brikker/nfc-ntag-produkter/) | One per card. Self-adhesive ø25 mm stickers embed easily in a printed card. We only read the **UID**, so cheap tags are fine. |

## Controls (the panel)

| # | Part | Qty | ≈ price | Buy (BerryBase first, DK alt.) | Notes |
|---|---|-----|---|-----|---|
| 6 | **KY-040 rotary encoder** w/ breakout (6 mm knurled shaft, with thread & nut) | 5 | €1.60 ea | [BerryBase](https://www.berrybase.de/en/rotary-encoder-with-breakout-board) | One volume knob per room slot (3 used + 2 spare). 20 pulses/rev, onboard pull-ups, threaded bushing for panel mount. Pins CLK(A)/DT(B)/SW/+/GND — we use CLK, DT, GND (ignore SW). Print the knobs. |
| 7 | **DSQ14 latching push-switch**, square 14×14 mm (push-on/push-off) | 7 | from €0.77 ea | [BerryBase](https://www.berrybase.de/druckschalter-quadratisch-schliesser) | 5 room-arm + shuffle + repeat. **Latching** (2-position, *rastend*) — the cap **stays pressed in when active**, so position *is* the state (no LED) and it holds across power-off. 12 mm panel hole, SPST-NO (closed when in → active-LOW, matches `WIRING.md`). Fixed cap: label with a sticker / print a thin symbol cap. |
| 8 | **Square push-button** (Drucktaster quadratisch), momentary, 14×14 mm | 3 | ~€0.80 ea | [BerryBase](https://www.berrybase.de/drucktaster-quadratisch-schliesser) | Previous / play-pause / next — **momentary** (*Schließer*, springs back). **Same 14×14 mm body + 12 mm panel hole as the DSQ14 latching switches** (item 7), so the whole panel matches and wires identically. (The 12 mm round *PCB-mount* button is smaller and not panel-friendly — avoid for the faceplate.) |
| 9 | **KY-006 passive buzzer module** | 1 | €1.10 | [BerryBase](https://www.berrybase.de/ky-006-passives-buzzer-modul) | Audio feedback (chirps/error). **Passive** (PWM plays tones), 3-pin module: **S → GPIO18**, **− → GND** (middle pin unused). Beginner-friendly. *Not* the active "Signalgeber" / "16 tones" types, which only play one fixed tone. |

## Wiring & passives

| # | Part | Qty | ≈ price | Buy (BerryBase first, DK alt.) | Notes |
|---|---|-----|---|-----|---|
| 10 | Breadboard (830-point) | 1 | €2–6 | [BerryBase (830)](https://www.berrybase.de/breadboard-mit-830-kontakten) · [arduinotech](https://arduinotech.dk/shop/breadboard-830-points/) | Prototype before soldering. |
| 11 | Dupont jumper set, 40-pin **F-F / M-M / F-M**, 20 cm | 1 | €4.90 | [BerryBase Dupont set](https://www.berrybase.de/en/40pin-jumper-dupont-cable-set-1x-f-f-m-m-f-m-each-20cm) | **Essential:** the Pi Zero header is **male**, so you need **F-M** wires to reach the breadboard — a plain M-M kit can't. This set has all three types. (Optional extra: the [65-cable solid M-M kit](https://www.berrybase.de/jumper-kabel-kit-set-mit-65-kabeln-in-4-laengen-fuer-breadboards) for tidy breadboard runs.) |
| 12 | Hook-up wire, 0.14 mm² (10 m spool) | 1–2 | €1.50 ea | [BerryBase Kupferlitze 10m (black)](https://www.berrybase.de/kupferlitze-isoliert-1x0-14mm-10m/farbe-schwarz) | Single-strand insulated wire for the final soldered build. One 10 m spool is enough length; a **2nd colour for ground** (e.g. black=GND + one other) makes wiring much easier to trace. (Or the [10-colour set](https://www.berrybase.de/kupferlitze-isoliert-0-14-mm2-set-10x10m) if you want the full rainbow.) |
| 13 | (Optional) Resistor assortment, 525-pc | 1 kit | €6–9 | [BerryBase 525-pc metal-film set](https://www.berrybase.de/525-teiliges-metallschichtwiderstands-sortiment-in-kunststoffbox/) | Buttons use the Pi's internal pull-ups, so likely none needed for v1. Handy to have. |
| 14 | (Optional) Pi Zero proto/HAT board | 1 | €4–8 | [BerryBase (permanent 830 PCB)](https://www.berrybase.de/permanent-pcb-breadboard-mit-830-kontakten-schwarz) · [raspberrypi.dk](https://raspberrypi.dk/en/shop/category/raspberry-pi-zero-and-accessories/) | Tidy permanent wiring instead of loose solder. |

## Battery / portability (optional, deferred — NOT part of the v1 wall-powered build)

v1 is wall-powered (item 3 PSU) — **skip this whole section for the first order.** It's here for
if you later want to **carry the box around** (README open question #8). Two documented options;
pair *either* with the **read-only root filesystem** (see README) so a flat pack / yanked cable
can't corrupt the SD card.

### Option A — rechargeable AA (NiMH)

No lithium in a printed case, cells **hot-swap** (keep a charged spare set), core parts all at
BerryBase. **4× AA + a 5V buck-boost** feeds the Pi's 5V. Runtime ≈ **8 h** (4× 2000 mAh ≈
9.6 Wh, ~1 W draw). No fuel gauge → no auto-shutdown; the box plays a **low-battery buzzer cue**.

| # | Part | Qty | ≈ price | Buy | Notes |
|---|---|-----|---|-----|---|
| B1 | **5V buck-boost regulator**, fixed 5V, ~2–3 A | 1 | €13–16 | [Pololu S13V30F5 (BerryBase)](https://www.berrybase.de/pololu-5v-step-up-step-down-spannungsregler-s13v30f5) | ⚠️ Must be **buck-boost** (auto step-up/**down**), *not* a plain step-up. **4 fresh NiMH ≈ 5.2–5.4 V — above 5 V** — sagging to ~4 V when low; only a buck-boost holds a clean **fixed 5 V** across that range (this one: 2.8–22 V in). Feed its 5 V into the Pi's micro-USB. (*Simpler/cheaper alt:* **3× AA** stays <5 V → a plain step-up works, ~25% less runtime.) |
| B2 | **Panasonic eneloop AA NiMH 2000 mAh**, 4-pack | 2 | €10–12 ea | [BerryBase eneloop AA 2000mAh ×4](https://www.berrybase.de/panasonic-eneloop-akku-mignon-aa-nimh-2000mah-4er-blister) | One set in the box + **one charged spare** for hot-swap. (Higher capacity: [eneloop Pro 2500mAh](https://www.berrybase.de/panasonic-eneloop-pro-akku-mignon-aa-nimh-2500mah-4er-blister), fewer charge cycles.) |
| B3 | **4× AA battery holder** w/ switch + leads | 1 | €1–2 | [BerryBase 4× AA holder, switched, cabled](https://www.berrybase.de/batteriehalter-fuer-4x-mignon-aa-mit-150mm-anschlusskabel-geschlossenem-gehaeuse-und-schalter-wasserabweisend) | Cells in series → ~4.8 V into B1. The integrated **switch doubles as the box's power switch**. (Plain cabled holder without switch also fine: [4× AA 150 mm leads](https://www.berrybase.de/batteriehalter-fuer-4x-mignon-aa-2-2-mit-150mm-anschlusskabel).) |
| B4 | **AA NiMH charger** | 1 | €15–22 | [BerryBase eneloop Smart & Quick BQ-CC55](https://www.berrybase.de/en/panasonic-eneloop-smart-quick-charger-bq-cc55) | Charges cells **out of the box** (NiMH needs −ΔV termination; no in-place charging). Per-slot charging. Any AA charger you own works just as well. |

**Seamless hot-swap (optional add-on to Option A).** B1–B4 alone mean *swapping power reboots
the Pi* (harmless under read-only root, just not gapless). For true no-reboot wall↔battery
hand-over, add an auto-switching power mux between the two 5V sources:

| # | Part | Qty | ≈ price | Buy | Notes |
|---|---|-----|---|-----|---|
| B5 | **Auto-switching power mux** (TPS2113A) | 1 | ~€11 | [Pololu TPS2113A carrier — **Opencircuit (NL, EU)**](https://opencircuit.shop/product/tps2113a-power-multiplexer-carrier-usb-micro-b) · [Pololu #2596](https://www.pololu.com/product/2596) | ⚠️ **Not stocked at BerryBase** — order from Opencircuit (EU, no customs). Wall PSU → board's micro-USB input; B1's 5V → other input; board output → Pi **5V GPIO pin 2 + GND pin 6**. Priority to wall, make-before-break → no reboot, blocks reverse current. Inputs 2.8–5.5 V, 2 A. |
| B6 | (optional) Bulk hold-up cap, ~470 µF / 10 V+ | 1 | ~€0.30 | BerryBase electrolytics | Insurance across the switch; B5 + the Pi's onboard caps usually suffice. |

> **Option A totals:** reboot-on-swap (B1–B4) ≈ **€50–65**, **all BerryBase**. Seamless adds B5
> (~€11, the one non-BerryBase part) → ≈ **€65–80** across two EU orders. Cells + charger are
> reusable across other devices.

### Option B — LiPo + PiSugar 3

A **clip-on UPS** board that connects to the Pi's underside via pogo pins, so it **doesn't touch
the 40-pin GPIO header**. Brings charge-in-place over USB, an **I²C fuel gauge**, an RTC, and
**seamless** wall↔battery switchover **built in** — the cheapest route to gapless hot-swap, and
the least wiring. Downsides: a **lithium cell inside the printed enclosure**, the stock cell is
1200 mAh (~3 h; swappable for a larger one), and it ships from outside the EU.

| # | Part | Qty | ≈ price | Buy | Notes |
|---|---|-----|---|-----|---|
| P1 | **PiSugar 3** (1200 mAh, Pi Zero form factor) | 1 | ~€40 + import (≈ €45–55 landed) | [pisugar.com](https://www.pisugar.com/products/pisugar-3-raspberry-pi-zero-battery) · [Tindie](https://www.tindie.com/products/pisugar/pisugar-3-battery-for-raspberry-pi-zero/) · [Amazon](https://www.amazon.com/PiSugar-Portable-Pwnagotchi-Management-Raspberry/dp/B0FB3N1YSK) | ⚠️ **Not at BerryBase**; ships from outside the EU (expect import VAT/handling). UPS + I²C gauge + RTC + pogo-pin mount. The I²C gauge makes a clean **auto-shutdown** easy. |

> **Option B total:** **≈ €45–55** landed, single board. Simplest seamless option; the trade is
> lithium-in-the-case and the shorter stock runtime.

## Tools (if you don't have them)

| # | Part | ≈ price | Buy | Notes |
|---|---|---|-----|---|
| 15 | Soldering station (temp-controlled) | €33 | [BerryBase goobay AP2 analog station, 48W](https://www.berrybase.de/goobay-ap2-analoge-loetstation-48w/) | Dial temperature control + stand — the right amount of tool for this. Step up: [Fixpoint EP5 digital](https://www.berrybase.de/en/fixpoint-ep5-digital-soldering-station-with-set-and-actual-temperature-display) (€75). Step down: [4-pc 30W set](https://www.berrybase.de/4-teiliges-loetset-bestehend-aus-30w-loetkolben-entloetpumpe-loetkolbenablage) (unregulated). |
| 16 | Solder, lead-free | €3–15 | [goobay 1.0mm 17g dispenser (~€3)](https://www.berrybase.de/goobay-loetzinn-bleifrei-oe1-0mm) · [0.56mm 100g roll (~€15)](https://www.berrybase.de/goobay-loetzinn-bleifrei-oe0-56mm-100g-rolle) | You only need a little for one box, so the small **17 g dispenser** is enough (1.0 mm = slightly thick). The **0.56 mm 100 g roll** is thinner/easier and a buy-once. (Lead-free silver solder runs pricey — don't be surprised by larger rolls at €25+.) |
| 17 | Wire stripper + side cutter | €6–12 | [BerryBase auto stripper + cutter](https://www.berrybase.de/en/automatik-abisolierzange-mit-integriertem-kabelschneider) | Strips and cuts in one tool. |
| 18 | (Nice) Multimeter | €15–30 | [BerryBase UNI-T UT131A](https://www.berrybase.de/uni-t-ut131a-digitales-multimeter-palm-size-mit-2mf-kapazitaetsmessung) | For continuity / voltage checks. Kjell (walk-in in DK) is a fine alternative. |
| 19 | (Optional) Desoldering pump | €2–4 | [BerryBase Entlötpumpe](https://www.berrybase.de/en/entloetpumpe-mit-hoher-saugleistung-teflonspitze) | Fixes solder blobs/bridges — handy while learning. |

## 3D printed (you make these — no purchase)

- Enclosure (case + faceplate with holes for buttons, encoders, card spot, buzzer grille).
- 3 knobs (fit EC11 6 mm knurled shaft).
- Button caps — incl. multi-material/multi-colour **shuffle/repeat symbol caps** and the
  **room-name caps** if you print labels rather than apply stickers.
- A card spot/tray and the cards themselves (NTAG215 sticker inside each).

---

## Where to buy

**Recommended — one EU order, ships to DK, no customs:**
- **[BerryBase.de](https://www.berrybase.de/en/)** — stocks the Pi board, PN532, NTAG215
  packs, encoders, switches, piezo, breadboard and wires: the **whole electronics build in
  one order** (the **Buy** column above links each item). Ships from Germany.

**Danish, fast (good alternates / pickup):**
- **[raspberrypi.dk](https://raspberrypi.dk/)** — Pi Zero 2 W (WH), microSD, official PSU, case (items 1–3).
- **[let-elektronik.dk](https://let-elektronik.dk/rfid-nfc-tags-sensorer)** — wide hobby range: PN532/NFC, encoders, buttons, buzzer, breadboard, jumpers, resistors (items 4, 6–13).
- **[elektronik-lavpris.dk](https://elektronik-lavpris.dk/)** — general hobby electronics, often cheap (PN532, buttons, passives).
- **[bitbyg.dk](https://bitbyg.dk/shop/pn532-nfc-rfid-module-v3/)** / **[ebits.dk](https://ebits.dk/products/pn532-rfid-laeser-inkl-noglekort-og-noglebrik)** — PN532 module.
- **[idekort.dk](https://idekort.dk/vare-kategori/rfid-og-kontaktloese-kort-og-brikker/nfc-ntag-produkter/)** — bulk NTAG213/215/216 tags & cards (item 5).
- **[arduinotech.dk](https://arduinotech.dk/shop/ntag-rfid-nfc-tag-smartphones/)** — NTAG215 tags, Arduino-style modules.
- **Kjell & Company** (kjell.com/dk, **physical stores** in DK) — soldering iron, wires, tools (items 15–18) if you'd rather walk in and buy today than wait for the BerryBase order.

**If the Pi is out of stock everywhere:** check **[amazon.de](https://www.amazon.de/Raspberry-Pi%C2%AE-Zero-512-1-0/dp/B0DB2JBD9C)**
(watch for third-party markup over RRP), **[Farnell](https://dk.farnell.com/)**, **POWER.dk**,
**Dustin.dk**, or compare on **[PriceRunner](https://www.pricerunner.dk/pl/10012-3208416724/Single-board-computere/Raspberry-Pi-Zero-2-W-Zero-2-Sammenlign-Priser)**.

> **Rough total:** **≈ €55–75** for the electronics + tags, plus **≈ €40–95** of tools if
> you're starting from zero — all in a single BerryBase order. Filament/enclosure: already covered.

---

## Does it fit the Pi? (GPIO budget)

The Pi Zero W and Zero 2 W share the same 40-pin header — **26 usable GPIO**. With 5 room
slots and latching buttons (no LEDs) this design needs **23** — it fits, with 3 to spare:

| Function | Pins | Suggested BCM (finalise at wiring) |
|---|---|---|
| PN532 (I²C) | 2 | GPIO2 (SDA), GPIO3 (SCL) |
| 5× encoder (A/B) | 10 | 17/27, 22/23, 24/25, 12/16, 20/21 |
| 7× latching button (5 room, 2 mode) | 7 | 4, 5, 6, 13, 19, 26, 7 |
| 3× momentary button (transport) | 3 | 8, 9, 10 |
| Piezo buzzer (PWM) | 1 | GPIO18 (hardware PWM) |

(All buttons use internal pull-ups — no resistors. Latching buttons mean their GPIO
level directly reflects armed/active state, and the Pi reads them at boot. The 5 room
slots cover the 3 current speakers plus 2 for future expansion. The exact pin-to-pin
connections are in **[`WIRING.md`](WIRING.md)**.)

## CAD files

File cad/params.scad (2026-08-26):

// Every dimension for the Music Box, plus the derived values and the sanity
// checks that depend on them. Included by every other file.

/* ---------------------------------------------------------------- box ---- */
// Width and depth are set by the 830-point breadboard (165 x 55) with the Pi
// behind it. The plate is as thin as the card groove allows, which also leaves
// the controls' bushings enough thread and their nuts in the open — no pockets
// needed anywhere.

W          = 185;
D          = 118;
H          = 54;
corner_r   = 6;
chamfer    = 1.0;
wall       = 2.4;
floor_t    = 2.4;
plate_t    = 4.0;

shell_h    = H - plate_t;

lip_w      = 1.6;   // plate's locating lip
lip_h      = 3.0;
lip_clear  = 0.4;   // per side; 0.25 is too tight across 185 mm

/* ------------------------------------------------------------- screws ---- */
// M3 flat-head from the top into M3 brass heat-set inserts in the posts.

post_r        = 5.0;
post_inset    = wall + lip_w + post_r;   // keeps the lip ring clear of the posts
insert_hole_d = 4.6;   // for the M3 x 5 x 5.0 OD inserts on hand
insert_depth  = 5.5;
screw_hole_d  = 3.4;
screw_head_d  = 5.0;
screw_cb_deep = 2.0;   // 3 mm head, so it stands 1 mm proud; 0 = on the surface

/* ------------------------------------------------------------ buttons ---- */
// The switches mount from the front: square bezel on the top face, ø11.6 barrel
// through the hole, nut and washer tightened from inside. The encoder is the other
// way round — 12x12 base inside, nut on top. Bushings measure 7.5 and 7.0 long,
// threaded end to end, so a 4 mm plate leaves 3.5 and 3.0 mm — exactly nut (2) +
// washer (1.5) on the switches.

btn_hole_d = 11.8;   // ø11.6 bushing + 0.2
btn_barrel = 13.0;   // round body behind the plate, keep-out for the preview
btn_body_h = 30.0;   // bezel back to the terminals, wires included


/* ------------------------------------------------------------ encoder ---- */
// KY-040 breakout, EC11 with a bare 6 mm knurled shaft. Its 12x12 base sits flat
// against the plate's underside; the nut does the holding. The bushing measures
// ø6.8, not the nominal M7.

enc_hole_d   = 7.0;   // ø6.8 bushing + 0.2
enc_board    = [19, 26];   // keep-out for the preview
enc_board_h  = 20;

// A printed knob presses onto the shaft. Prints top-face down, so the bore and
// the nut recess open upward and nothing overhangs.
knob_d        = 18;     // over the ridges; the nut recess sets the lower limit
knob_ch       = 1.0;    // top-edge chamfer
knob_gap      = 0.5;    // knob underside to plate
knob_top      = 1.2;    // skin over the end of the shaft
knob_nut_d    = 12.5;   // recess that swallows the encoder's nut (verify: across
                        // corners, ~11.5 for a 10 mm across-flats nut)
knob_nut_min  = 3.5;    // depth the nut alone needs
knob_flutes   = 14;
knob_flute_d  = 2.4;

// Measured shaft: ø6, standing 15.5 above the plate, with the flat cut over the
// top 10 mm only. The bore can only grip where that flat is, so the nut recess is
// deepened to clear the round stretch and the D starts at the recess floor.
knob_shaft_up   = 15.5;
knob_shaft_d    = 6.0;
knob_shaft_flat = 4.5;   // thickness across the flat; 0 = a plain round shaft
knob_shaft_flat_len = 10;
knob_flat_margin = 0.5;  // start the D this far below where the flat should begin,
                         // so a slightly longer round stretch can't jam the knob
knob_bore_fit = 0.0;    // press fit, no glue: printed holes come out undersize
                        // anyway. Raise to 0.1 if it will not go on.

knob_bore_h  = knob_shaft_up - knob_gap;   // the shaft is fully swallowed
// The shaft is round below its flat, so the bore can't grip there. Rather than a
// useless round step in front of the D, the nut recess is deepened to clear that
// stretch — so the flat starts right at the recess floor.
knob_round_h = max(0, knob_bore_h - knob_shaft_flat_len);
knob_flat_z  = knob_round_h > 0 ? knob_round_h + knob_flat_margin : 0;
knob_nut_h   = max(knob_nut_min, knob_flat_z);
knob_h       = knob_bore_h + knob_top;

vol_mark_off  = 14;   // as engraved on the first plate — don't move it
if (knob_d / 2 > vol_mark_off - 3.0)
    echo(str("WARNING: a ø", knob_d, " knob overlaps the volume marks at ",
             vol_mark_off, " — max is ø", 2 * (vol_mark_off - 3.0)));
// the flutes are centred on the rim, so they cut half their diameter deep
knob_valley_r = knob_d / 2 - knob_flute_d / 2;
if (knob_valley_r - knob_nut_d / 2 < 1.2)
    echo(str("WARNING: only ", knob_valley_r - knob_nut_d / 2,
             " mm of wall between the flute valleys and the nut recess"));

/* --------------------------------------------------------- card / NFC ---- */
// The card's rim drops into a groove in the plate: it keeps a written title
// square, marks the spot when empty, and bridges in ~4 mm so the plate can print
// face down. The plate is NOT thinned here — PLA is transparent at 13.56 MHz, so
// only distance matters, and the tag ends up plate_t + pn532_standoff = 9 mm from
// the coil, well inside a PN532's range.

// If the rim ends up tight in the groove, shrink card_size rather than opening up
// the groove — the card is the cheap part to reprint.
card_seat_clear = 0.4;    // around the rim, per side
card_seat_h     = 2.2;    // groove depth
// A whole number of extrusions wide, so the slicer fills the rim with walls and
// nothing else. At 3.0 it came to six walls plus a 0.3 mm ribbon of gap fill,
// laid down right behind the outer wall on every layer of the rim — that is what
// dents the card's edge at the height where the solid part ends and only the rim
// carries on. Set extrusion_w to the slicer's own value and reslice.
extrusion_w     = 0.45;   // 0.4 nozzle, PrusaSlicer's default width
card_rim_walls  = 6;
card_rim_w      = card_rim_walls * extrusion_w;
card_rim_h      = 2.0;
// Both of the rim's bottom edges are rounded over. Stacked cards rest
// rim-on-label, and a square 2 mm lip digs under the edge of the label on the
// card below as soon as the stack slides. Only the bottom ~0.3 mm of the rim's
// profile — the label's own thickness — ever touches it, so what matters is the
// shape right at the tip, not how far up the relief runs: a fillet meets the
// label tangentially, where a chamfer would present its lower arris at 45. The
// rim never bottoms out in the groove (card_seat_h > card_rim_h), so the thinned
// tip carries no load, and the rim faces up on the bed, so this is free to print.
card_rim_r      = 0.8;

// Two mounting holes on a diagonal 38 mm apart, symmetric about the card spot so
// the antenna stays centred. If the diagonal isn't 45 deg, measure dx/dy between
// the holes and set the angle to atan2(dy, dx).
pn532_pcb        = [43, 41];   // (verify)
pn532_hole_span  = 37.5;
pn532_hole_angle = 45;
// Posts sized for an M3x8 self-tapping into PLA: 1.6 through the PCB leaves 6.4,
// and the pilot runs 1 mm into the plate so the tip can't bottom out. 2.8 pilot —
// 2.5 needs more torque than a printed post will take.
pn532_hole_d     = 2.8;
pn532_hole_deep  = 1.0;   // how far the pilot runs on into the plate
pn532_standoff   = 6.0;
pn532_post_r     = 3.5;

/* -------------------------------------------------------------- buzzer --- */
// The can drops into a pocket so its output sits right behind the grille, leaving
// 1 mm of plate for the holes. Two fences flank the PCB; tape or glue it.

buzz_pcb          = [19.2, 15.2];
buzz_can_d        = 13.4;         // ø13 can + fit
buzz_can_h        = 8.3;
buzz_can_deep     = 3.0;          // how far the can sinks into the plate
buzz_grille_d     = 1.8;
buzz_grille_pitch = 4.0;
buzz_grille_n     = 3;
buzz_fence        = [2, 12];

/* ---------------------------------------------------------------- feet --- */

foot_d     = 12;
foot_deep  = 0.5;
foot_inset = 16;

/* ----------------------------------------------------------- breadboard -- */
// Lies flat on the floor across the front, located by four corner ribs; it comes
// out again when the build moves to soldered wiring.

bb         = [165, 55, 9.5];
bb_pos     = [W / 2, 45];
bb_clear   = 0.6;
bb_rib_h   = 4.0;
bb_rib_t   = 2.0;
bb_rib_l   = 14;

/* ------------------------------------------------------------------ Pi --- */
// Drops onto printed pegs through its own mounting holes, with three snap clips.
// No hardware: M3 will not pass through the Pi's 2.75 mm holes. The clips flex
// 0.6 mm over ~7 mm, so they stay thin or PLA cracks. microSD needs the plate off.

pi_pcb        = [65, 30];
pi_holes      = [58, 23];
pi_pcb_t      = 1.6;
pi_standoff_h = 4.0;
pi_post_r     = 3.0;
pi_peg_d      = 2.5;   // Pi hole is 2.75; sand if it prints tight
pi_peg_h      = 3.2;
pi_clip_t     = 1.2;
pi_clip_w     = 9;
pi_clip_hook  = 0.6;
pi_clip_gap   = 0.4;
pi_pos        = [51, 95];   // rear left, behind the breadboard
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

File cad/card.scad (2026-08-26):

// The printed NFC card: tag recess and the rim that drops into the faceplate's
// groove.
include <params.scad>
include <util.scad>

module card() {
    difference() {
        union() {
            // bottom face at z = 0; flipped for the bed in the part switch
            rbox_ch(card_size[0], card_size[1], card_t, card_r, card_ch);
            // rim, into the plate's groove. Both bottom edges are rounded over,
            // so the surface that meets the label of the card below is tangent to
            // the label's own plane — there is no arris anywhere to dig under it.
            translate([0, 0, -card_rim_h]) difference() {
                f  = card_rim_r;
                iw = card_size[0] - 2 * card_rim_w;
                id = card_size[1] - 2 * card_rim_w;
                ir = max(0.5, card_r - card_rim_w);
                union() {
                    rbox_profile(card_size[0], card_size[1], card_r, fillet_prof(f));
                    translate([0, 0, f])
                        rbox(card_size[0], card_size[1], card_rim_h - f, card_r);
                }
                translate([card_rim_w, card_rim_w, 0]) union() {
                    translate([-f, -f, -0.5]) rbox(iw + 2 * f, id + 2 * f, 0.5, ir + f);
                    rbox_profile(iw, id, ir, fillet_prof(f, sign = -1));
                    translate([0, 0, f]) rbox(iw, id, card_rim_h + 0.5 - f, ir);
                }
            }
        }
        translate([card_size[0] / 2, card_size[1] / 2, -0.5])
            cylinder(d = tag_d, h = tag_recess + 0.5);
    }
}

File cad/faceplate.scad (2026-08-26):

// The top plate: panel holes, the card groove, the PN532 posts, the buzzer
// pocket and fences, the screw counterbores and the engraved icons.
include <params.scad>
include <util.scad>
include <icons.scad>

module lip() {
    difference() {
        translate([wall + lip_clear, wall + lip_clear, -lip_h])
            rbox(W - 2 * (wall + lip_clear), D - 2 * (wall + lip_clear),
                 lip_h, max(0.5, corner_r - wall - lip_clear));
        translate([wall + lip_clear + lip_w, wall + lip_clear + lip_w, -lip_h - 1])
            rbox(W - 2 * (wall + lip_clear + lip_w), D - 2 * (wall + lip_clear + lip_w),
                 lip_h + 2, max(0.5, corner_r - wall - lip_clear - lip_w));
        for (p = post_pts()) translate([p[0], p[1], -lip_h - 1])
            cylinder(r = post_r + 0.3, h = lip_h + 2);
    }
}

module btn_hole(pos) {
    translate([pos[0], pos[1], -1]) cylinder(d = btn_hole_d, h = plate_t + 2);
}

module enc_hole(pos) {
    translate([pos[0], pos[1], -1]) cylinder(d = enc_hole_d, h = plate_t + 2);
}

// channel the card's rim drops into
module card_groove() {
    ow = card_size[0] + 2 * card_seat_clear;
    od = card_size[1] + 2 * card_seat_clear;
    iw = card_size[0] - 2 * (card_rim_w + card_seat_clear);
    id = card_size[1] - 2 * (card_rim_w + card_seat_clear);
    translate([0, 0, plate_t - card_seat_h]) difference() {
        translate([card_pos[0] - ow / 2, card_pos[1] - od / 2, 0])
            rbox(ow, od, card_seat_h + 1, card_r + card_seat_clear);
        translate([card_pos[0] - iw / 2, card_pos[1] - id / 2, -0.5])
            rbox(iw, id, card_seat_h + 2,
                 max(0.5, card_r - card_rim_w - card_seat_clear));
    }
}

module faceplate() {
    difference() {
        union() {
            rbox_ch(W, D, plate_t, corner_r, chamfer);
            lip();
            for (p = pn532_hole_pts())
                translate([p[0], p[1], -pn532_standoff])
                    cylinder(r = pn532_post_r, h = pn532_standoff);
            fh = buzz_can_h - buzz_can_deep + 2.6;   // past the PCB
            for (sx = [-1, 1])
                translate([buzz_pos[0] + sx * (buzz_pcb[0] + 0.6 + buzz_fence[0]) / 2
                           - buzz_fence[0] / 2,
                           buzz_pos[1] - buzz_fence[1] / 2, -fh])
                    cube([buzz_fence[0], buzz_fence[1], fh]);
        }

        btn_hole(toggle_pos);
        btn_hole(prev_pos);
        btn_hole(play_pos);
        btn_hole(next_pos);
        enc_hole(enc_pos);

        card_groove();

        for (p = pn532_hole_pts())
            translate([p[0], p[1], -pn532_standoff - 0.01])
                cylinder(d = pn532_hole_d, h = pn532_standoff + pn532_hole_deep);

        translate([buzz_pos[0], buzz_pos[1], -0.5])
            cylinder(d = buzz_can_d, h = buzz_can_deep + 0.5);
        for (i = [0 : buzz_grille_n - 1], j = [0 : buzz_grille_n - 1])
            translate([buzz_pos[0] + (i - (buzz_grille_n - 1) / 2) * buzz_grille_pitch,
                       buzz_pos[1] + (j - (buzz_grille_n - 1) / 2) * buzz_grille_pitch,
                       -1])
                cylinder(d = buzz_grille_d, h = plate_t + 2);

        for (p = post_pts()) translate([p[0], p[1], 0]) {
            translate([0, 0, -1]) cylinder(d = screw_hole_d, h = plate_t + 2);
            if (screw_cb_deep > 0)
                translate([0, 0, plate_t - screw_cb_deep])
                    cylinder(d = screw_head_d + 0.4, h = screw_cb_deep + 1);
        }

        icons();
    }
}

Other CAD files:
cad/icons.scad
cad/jigs.scad
cad/knob.scad
cad/musicbox_single.scad
cad/shell.scad
cad/storage.scad
cad/util.scad

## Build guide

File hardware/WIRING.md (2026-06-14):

# Wiring guide

Exact pin-to-pin connections for the Music Box on a **Raspberry Pi Zero 2 W**
(standard 40-pin header). This finalises the provisional pin budget in
[`BOM.md`](BOM.md): **5 room slots** (3 speakers today + 2 spare), 2 mode buttons,
3 transport buttons, the PN532 NFC reader, and the piezo — **23 of 26 usable GPIO**.

> **Breadboard first, solder later.** Wire everything on a breadboard and prove it
> (test steps at the bottom) before committing solder. Nothing here needs resistors:
> buttons use the Pi's internal pull-ups, the PN532 has its own I²C pull-ups.

## Safety / ground rules

- **Power off the Pi while wiring.** Plug in only to test.
- **The Pi's GPIO is 3.3 V logic — never feed 5 V into a GPIO pin.** The PN532 runs
  from the **3V3** pin (not 5V). Buttons/encoders only switch to **GND**, so they
  can't over-volt anything.
- The Pi has **8 GND pins** but we need ~16 ground connections. Run a **common ground
  bus** (a breadboard ground rail) from one or two Pi GND pins, and land every
  component ground on that rail.
- Pins **27 (GPIO0)** and **28 (GPIO1)** are reserved for HAT EEPROM ID — leave empty.

---

## Pin map (what connects where)

BCM = the GPIO number you use in software. Pin = the physical position on the 40-pin
header (count along the board; pin 1 is the corner nearest the SD card / marked with a
square pad).

| Function | Connects to | BCM | Header pin |
|---|---|-----|---|
| **PN532** VCC | 3V3 | — | **1** |
| **PN532** GND | ground bus | — | (any GND) |
| **PN532** SDA | I²C data | GPIO2 | **3** |
| **PN532** SCL | I²C clock | GPIO3 | **5** |
| **Room 1 (Alrum)** button | → GND | GPIO4 | **7** |
| **Room 2 (Køkken)** button | → GND | GPIO5 | **29** |
| **Room 3 (Grys værelse)** button | → GND | GPIO6 | **31** |
| **Room 4 (spare)** button | → GND | GPIO13 | **33** |
| **Room 5 (spare)** button | → GND | GPIO19 | **35** |
| **Shuffle** button | → GND | GPIO26 | **37** |
| **Repeat** button | → GND | GPIO7 | **26** |
| **Previous** button | → GND | GPIO10 | **19** |
| **Play / Pause** button | → GND | GPIO9 | **21** |
| **Next** button | → GND | GPIO8 | **24** |
| **Vol 1 (Alrum)** encoder A / B | → GPIO | GPIO17 / GPIO27 | **11 / 13** |
| **Vol 2 (Køkken)** encoder A / B | → GPIO | GPIO22 / GPIO23 | **15 / 16** |
| **Vol 3 (Grys)** encoder A / B | → GPIO | GPIO24 / GPIO25 | **18 / 22** |
| **Vol 4 (spare)** encoder A / B | → GPIO | GPIO12 / GPIO16 | **32 / 36** |
| **Vol 5 (spare)** encoder A / B | → GPIO | GPIO20 / GPIO21 | **38 / 40** |
| **Piezo** (+) | PWM | GPIO18 | **12** |
| **Piezo** (−) | ground bus | — | (any GND) |

Every encoder's **common (C)** pin → ground bus. Each button's **second terminal** →
ground bus. That's the whole pattern: signal pin to its GPIO, the other side to ground.

---

## Header layout (annotated)

```
                    3V3  (1) ● ● (2)  5V
        PN532 SDA  GPIO2  (3) ● ● (4)  5V
        PN532 SCL  GPIO3  (5) ● ● (6)  GND ── ground bus
      Room1 btn    GPIO4  (7) ● ● (8)  GPIO14   ·free·
                    GND   (9) ● ● (10) GPIO15   ·free·
      Vol1 A      GPIO17 (11) ● ● (12) GPIO18 ── Piezo (+)
      Vol1 B      GPIO27 (13) ● ● (14) GND ──── ground bus
      Vol2 A      GPIO22 (15) ● ● (16) GPIO23 ── Vol2 B
                    3V3  (17) ● ● (18) GPIO24 ── Vol3 A
      Prev btn    GPIO10 (19) ● ● (20) GND ──── ground bus
      Play btn     GPIO9 (21) ● ● (22) GPIO25 ── Vol3 B
      ·free·      GPIO11 (23) ● ● (24) GPIO8 ─── Next btn
                    GND  (25) ● ● (26) GPIO7 ─── Repeat btn
   ·reserved·      GPIO0 (27) ● ● (28) GPIO1    ·reserved·
      Room2 btn    GPIO5 (29) ● ● (30) GND ──── ground bus
      Room3 btn    GPIO6 (31) ● ● (32) GPIO12 ── Vol4 A
      Room4 btn   GPIO13 (33) ● ● (34) GND ──── ground bus
      Room5 btn   GPIO19 (35) ● ● (36) GPIO16 ── Vol4 B
      Shuffle btn GPIO26 (37) ● ● (38) GPIO20 ── Vol5 A
                    GND  (39) ● ● (40) GPIO21 ── Vol5 B
```

---

## Per-component wiring

### PN532 NFC reader (I²C)
Most PN532 V3 boards have a **DIP switch or solder jumpers to pick the interface** —
set it to **I²C** (often "1=OFF, 2=ON"; check your board's silkscreen).

| PN532 pad | → Pi |
|---|---|
| VCC | 3V3 (pin 1) |
| GND | ground bus |
| SDA | GPIO2 / pin 3 |
| SCL | GPIO3 / pin 5 |

The board carries its own I²C pull-ups, so no resistors. Enable I²C with
`sudo raspi-config` → Interface Options → I²C.

### Buttons (5 room latching + 2 mode latching + 3 transport momentary)
All ten wire the **same way** — they're just switches:

```
   GPIO pin  ─────[ button ]─────  ground bus
```

One terminal to the listed GPIO, the other to ground. In software each pin uses an
**internal pull-up** (`pull_up=True`), so an open switch reads **HIGH (1)** and a
closed/latched-in switch reads **LOW (0)** — i.e. *active-low*.

- **Latching** room/mode buttons stay mechanically closed when "in", so their pin sits
  LOW for as long as the room is armed / mode is active — the Pi can read armed state
  directly, even right after boot.
- **Momentary** transport buttons read LOW only while held.

### Rotary encoders ×5 (EC11)
An EC11 has **two sides**: the rotary side (pins **A, C, B**) and an optional push-switch
side (2 pins). **We use only the rotary side**; leave the push-switch pins unconnected.

```
   A ── GPIO (listed "A")
   C ── ground bus            (common)
   B ── GPIO (listed "B")
```

Software enables internal pull-ups on A and B and watches their phase to tell
clockwise from counter-clockwise (relative steps → SoCo per-room volume). If you see
jitter on the breadboard, a small **0.1 µF cap from A→GND and B→GND** debounces it
(optional; try without first).

### Piezo buzzer (KY-006 passive module)
The KY-006 is a 3-pin passive buzzer module — wire two of them:

```
   S (signal) ── GPIO18 (pin 12)
   −          ── ground bus
   (middle pin: leave unconnected)
```

It's **passive**, so GPIO18's hardware PWM plays tones. A bare passive piezo element
works the same way (one leg → GPIO18, other → GND). If it's too quiet, drive it through
an NPN transistor (e.g. 2N2222: GPIO→1 kΩ→base, emitter→GND, collector→buzzer→3V3) —
not needed for v1.

---

## Suggested wiring order (breadboard)

1. **Ground bus + PN532 only.** Power on, `i2cdetect -y 1` should show the PN532
   (commonly at address `0x24`). Tap a tag and confirm a UID read with a test script.
2. **One button** (say Play/Pause, GPIO9). Confirm it reads LOW when pressed.
3. **One encoder** (Vol 1, GPIO17/27). Confirm turning it steps a counter up/down.
4. **Piezo** (GPIO18). Confirm a PWM tone plays.
5. Once each *type* works, replicate for the remaining buttons/encoders — same pattern,
   different pins from the table.

### Quick test snippets

```bash
# PN532 present on I²C?
sudo apt install -y i2c-tools
i2cdetect -y 1

# Button on GPIO9 + encoder on GPIO17/27 (uses gpiozero, preinstalled on Pi OS)
python3 - <<'PY'
from gpiozero import Button, RotaryEncoder
from signal import pause
play = Button(9)                       # active-low via internal pull-up
vol1 = RotaryEncoder(17, 27, max_steps=0)
play.when_pressed  = lambda: print("PLAY pressed")
vol1.when_rotated  = lambda: print("vol1 =", vol1.steps)
print("Press play / turn the encoder…")
pause()
PY
```

When all five families check out on the breadboard, transfer to soldered wiring (or a
Pi Zero proto/HAT board) for the enclosure build.

### Running the prototype software

- **One control at a time:** `software/spike_gpio.py` (button → buzzer) is the smallest
  end-to-end check — see its header for setup.
- **The whole box:** copy `software/hardware.example.json` → `hardware.json`, list the
  controls you've wired (it ships set up for the first prototype: buzzer, NFC, transport,
  one room slot on the pins above), then run `python -m musicbox.service`. That binds
  exactly those controls and serves the config app at `musicbox.local` to map the slot to
  a Sonos room and bind cards. **Add a control = add it to `hardware.json`, no code change.**

---

## Cross-references

- Parts & quantities: [`BOM.md`](BOM.md)
- Control behaviour (what each button does): the **Control scheme** section in the
  top-level [`README.md`](../README.md)
- The pin numbers above match the **GPIO budget** table in `BOM.md`; if you change one,
  change both.

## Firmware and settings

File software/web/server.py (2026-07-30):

"""The Music Box config app — what the box serves at musicbox.local.

  /          a start page linking to the two below
  /config    map each hardware room-slot → a Sonos room, and NFC tags → Sonos
             Favorites or playlists (live enrollment by holding a card on the box)
  /labels    lay album art onto a sheet of die-cut card labels, ready to print

`create_app(box, ...)` is an app factory so the same routes serve both a laptop
(this module's module-level `app`, used by `python -m web.server`) and the
on-device service (musicbox/service.py), which passes the *same* box + shared room
map the GPIO panel is using.

Run it on a laptop:  python -m web.server       (from the software/ directory)
"""

import json
import os
import sys

from flask import Flask, Response, jsonify, render_template, request

sys.path.insert(0, os.path.dirname(os.path.dirname(os.path.abspath(__file__))))
from musicbox.config import (  # noqa: E402
    load_card_map,
    load_room_map,
    save_card_map,
    save_room_map,
)
from musicbox.core import MusicBox  # noqa: E402
from musicbox.feedback import ConsoleBuzzer  # noqa: E402
from musicbox.hardware.profile import load_profile  # noqa: E402
from web import labelsheet  # noqa: E402


def create_app(box, *, profile=None, room_map=None, card_path=None, room_path=None,
               nfc_last=None, connected=True, connect_error=None):
    """Build the Flask app over a given MusicBox.

    room_map is a *live* dict shared with the caller (the GPIO panel on the Pi),
    so saving a new mapping here takes effect immediately for the hardware too.
    """
    app = Flask(__name__)
    room_map = room_map if room_map is not None else {}
    slot_ids = list(profile.slot_ids) if profile else []

    def favorites_list(refresh=False):
        try:
            return box.favorite_titles(refresh=refresh)
        except Exception:
            return []

    def playlists_list(refresh=False):
        try:
            return box.playlist_titles(refresh=refresh)
        except Exception:
            return []

    @app.get("/")
    def start_page():
        return render_template("index.html", connected=connected,
                               connect_error=connect_error or "")

    @app.get("/config")
    def config_page():
        return render_template("config.html")

    # --- configuration API --------------------------------------------------

    @app.get("/api/config")
    def get_config():
        # The config page is opened rarely and is exactly where a favorite added
        # in the Sonos app needs to show up, so re-read the list every time. It
        # also freshens the shared cache the playback path matches against.
        return jsonify({
            "sonos_rooms": box.rooms(),
            "slots": slot_ids,
            "room_map": dict(room_map),
            "cards": dict(box.card_map),
            "favorites": favorites_list(refresh=True),
            "playlists": playlists_list(refresh=True),
            "nfc_last": nfc_last() if nfc_last else None,
        })

    @app.post("/api/rooms")
    def save_rooms():
        data = request.get_json(force=True)
        new_map = data.get("room_map", {})
        valid = set(box.rooms())
        cleaned = {}
        for slot, room in new_map.items():
            if not room:
                continue  # blank = leave the slot unassigned
            if valid and room not in valid:
                return jsonify({"ok": False, "message": f"unknown Sonos room {room!r}"}), 400
            cleaned[str(slot)] = room
        room_map.clear()
        room_map.update(cleaned)  # mutate the shared dict in place so the panel sees it
        save_room_map(room_map, room_path)
        return jsonify({"ok": True, "message": "Room mapping saved.", "room_map": dict(room_map)})

    @app.post("/api/cards")
    def save_cards():
        data = request.get_json(force=True)
        cid = str(data.get("id", "")).strip()
        if not cid:
            return jsonify({"ok": False, "message": "Missing card id / tag UID."}), 400
        if data.get("action") == "delete":
            box.card_map.pop(cid, None)
            msg = f"Removed card {cid!r}."
        else:
            fav = str(data.get("favorite", "")).strip()
            if not fav:
                return jsonify({"ok": False, "message": "Pick a favorite to bind."}), 400
            box.card_map[cid] = fav  # the running box sees the new card immediately
            msg = f"Bound {cid!r} → {fav!r}."
        save_card_map(box.card_map, card_path)
        return jsonify({"ok": True, "message": msg, "cards": dict(box.card_map)})

    # --- card labels --------------------------------------------------------

    @app.get("/labels")
    def labels_page():
        return render_template("labels.html")

    @app.get("/api/labels/art")
    def label_art():
        """The artwork for one favorite. ?debug=1 returns the trace, not the image."""
        title = request.args.get("title", "")
        trace = []
        try:
            data = box.artwork_for(title, trace=trace)
        except Exception as e:
            trace.append(f"failed: {e}")
            data = None
        side = labelsheet.source_size(data) if data else 0
        trace.append(f"final size: {side}px")
        for line in trace:                      # goes to journalctl -u musicbox
            print(f"[art] {title!r}: {line}", flush=True)
        if request.args.get("debug"):
            return jsonify({"title": title, "px": side, "trace": trace})
        if not data:
            return jsonify({"ok": False, "message": "no artwork for that one"}), 404
        return Response(data, mimetype="image/jpeg",
                        headers={"X-Source-Px": str(side)})

    @app.post("/api/labels/pdf")
    def label_pdf():
        """Build the sheet. Each slot carries either a favorite title or a file."""
        images, soft = {}, []
        for slot in range(1, labelsheet.SLOTS + 1):
            upload = request.files.get(f"file{slot}")
            title = (request.form.get(f"title{slot}") or "").strip()
            if upload and upload.filename:
                data = upload.read()
            elif title:
                try:
                    data = box.artwork_for(title)
                except Exception:
                    data = None
                if not data:
                    return jsonify({"ok": False,
                                    "message": f"No artwork found for {title!r}. "
                                               f"Add an image for that label."}), 400
            else:
                continue
            if labelsheet.source_size(data) < labelsheet.MIN_PX:
                soft.append(slot)
            images[slot] = data

        calib = request.form.get("calib") == "1"
        if not images and not calib:
            return jsonify({"ok": False, "message": "Nothing chosen yet."}), 400
        bleed = float(request.form.get("bleed", 1.0))
        pdf = labelsheet.build_sheet(images, bleed=bleed, calib=calib)
        name = "labels-calibration.pdf" if calib else "labels.pdf"
        return Response(pdf, mimetype="application/pdf", headers={
            "Content-Disposition": f'inline; filename="{name}"',
            "X-Soft-Slots": ",".join(str(s) for s in soft),
        })

    @app.get("/api/nfc/last")
    def nfc_last_seen():
        return jsonify({"uid": nfc_last() if nfc_last else None})

    return app


def _build_sim_app():
    """The laptop simulator app: a fresh box that discovers Sonos at import."""
    box = MusicBox(card_map=load_card_map(), buzzer=ConsoleBuzzer())
    connected, error = True, None
    try:
        box.discover()
    except RuntimeError as e:
        connected, error = False, str(e)
    return create_app(
        box,
        profile=load_profile(),       # so the /config room-mapping demo has slots
        room_map=load_room_map(),
        connected=connected,
        connect_error=error,
    )


app = _build_sim_app()  # module-level for gunicorn (web.server:app) and `python -m web.server`


def main():
    port = int(os.environ.get("MUSICBOX_PORT", "8080"))
    print(f"Open http://localhost:{port}/   (setup · card labels)")
    app.run(host="0.0.0.0", port=port, debug=False)


if __name__ == "__main__":
    main()

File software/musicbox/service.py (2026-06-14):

"""The on-device service: the physical panel and the config web app, together.

This is what runs on the Pi (`python -m musicbox.service`). It builds one shared
`MusicBox`, wires the GPIO `Panel` to it, and serves the `musicbox.local` web app
over the *same* box and slot→room map — so remapping a room or binding a card in
the browser takes effect on the hardware immediately, and a card read by the
PN532 shows up in the enrollment page.

It degrades gracefully: if a hardware library or pin isn't available (e.g. you
run it on a laptop), that piece is skipped with a note and the rest still runs —
handy for poking at the web app off-device.
"""

import os
import sys

sys.path.insert(0, os.path.dirname(os.path.dirname(os.path.abspath(__file__))))
from musicbox.config import load_card_map, load_room_map  # noqa: E402
from musicbox.core import MusicBox  # noqa: E402
from musicbox.feedback import ConsoleBuzzer  # noqa: E402
from musicbox.hardware.panel import Panel  # noqa: E402
from musicbox.hardware.profile import load_profile  # noqa: E402
from web.server import create_app  # noqa: E402


def _build_buzzer(profile):
    if profile.buzzer_pin is None:
        return ConsoleBuzzer()
    try:
        from musicbox.hardware.buzzer import GpioBuzzer

        return GpioBuzzer(profile.buzzer_pin)
    except Exception as e:  # gpiozero missing / not on a Pi
        print(f"  buzzer: GPIO unavailable ({e}); using console buzzer")
        return ConsoleBuzzer()


def _build_nfc(profile):
    if not profile.nfc_enabled:
        return None
    try:
        from musicbox.hardware.nfc import Pn532Reader

        return Pn532Reader()
    except Exception as e:  # adafruit/i2c missing or no reader attached
        print(f"  nfc: PN532 unavailable ({e}); NFC reading disabled")
        return None


def _log(result):
    mark = "ok" if result.get("ok") else "!!"
    print(f"  [{mark}] {result.get('message', '')}")


def build(discover=True):
    """Assemble box + panel + web app. Returns (app, panel, box)."""
    profile = load_profile()
    room_map = load_room_map()  # shared live dict: panel and web both use it
    box = MusicBox(card_map=load_card_map(), buzzer=_build_buzzer(profile))

    connected, error = False, None
    if discover:
        print("Discovering Sonos speakers…")
        try:
            box.discover()
            connected = True
            print(f"  found: {', '.join(box.rooms())}")
        except RuntimeError as e:
            error = str(e)
            print(f"  not connected: {error}")

    panel = Panel(box, profile, room_map, nfc=_build_nfc(profile), on_change=_log)
    try:
        panel.bind()
        controls = len(panel._controls)
        print(f"  panel: {controls} control(s) bound; "
              f"slots={profile.slot_ids or '[]'}; nfc={'on' if panel.nfc else 'off'}")
    except Exception as e:  # gpiozero missing / not on a Pi
        print(f"  panel: GPIO unavailable ({e}); serving web only (no physical controls)")

    app = create_app(
        box,
        profile=profile,
        room_map=room_map,
        nfc_last=lambda: panel.last_uid,
        connected=connected,
        connect_error=error,
    )
    return app, panel, box


def main():
    app, panel, _ = build()
    port = int(os.environ.get("MUSICBOX_PORT", "8080"))
    suffix = "" if port == 80 else f":{port}"
    print(f"\nConfig + faceplate at http://musicbox.local{suffix}/  (setup: /config)")
    try:
        app.run(host="0.0.0.0", port=port, debug=False)
    finally:
        panel.stop()


if __name__ == "__main__":
    main()

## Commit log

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2026-06-06 Add transport buttons, no-room error beep, and a piezo buzzer
    Resolves the remaining control questions. Adds previous/next transport
    buttons. Defines that pressing play with no room armed is a deliberate
    no-op signalled by an error beep, rather than a silent failure or a
    surprise default room. Adds a GPIO piezo buzzer so a screenless device
    can give audio feedback (card recognized, arm/disarm, errors) — the Pi
    can drive this directly without the absent audio jack.
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2026-06-06 Add musicbox control package, CLI simulator, and logic tests
    Turns the proven spike into the real control core. The MusicBox class
    holds all Sonos logic (room arming/grouping, per-room volume, play
    modes, transport, card->favorite playback) with no UI or hardware
    dependency, so the CLI today, a web UI next, and GPIO buttons on the Pi
    later are all just thin front-ends over the same brain. The buzzer is
    abstracted the same way (console now, PWM tones on the Pi). Includes
    fake-speaker logic tests so the control flow is verifiable without a
    real Sonos on the network. Adds flask to requirements for the upcoming
    web UI.
    [cli.py, config.py, core.py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]
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2026-06-06 Add web UI simulator that looks like the physical box
    Adds a Flask single-page faceplate driving the same MusicBox core as the
    CLI, so we can see and feel the device before building it — and it
    doubles as a start on the "configure over the network" requirement. The
    panel mirrors the agreed controls: per-room arm switch + volume knob
    (level shown by pointer rotation, no numeric display), shuffle/repeat
    flips, prev/play/next, a card tray, and the card deck. The browser
    synthesises the buzzer cues from the same CUES patterns the Pi will use,
    and knobs are adjusted by click-and-drag. Ships the three requested
    cards (Bohemian Rhapsody, DR P6, Come Away With Me) in cards.json and a
    preview image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
    [server.py]
2026-06-06 Controls become illuminated press buttons with labels on the caps
    Captures the final control form reached while iterating on the
    simulator: room arm and shuffle/repeat are illuminated push-buttons
    rather than flip switches, the room label lives on the button cap (the
    box ships unlabelled), and shuffle/repeat carry their symbol raised in a
    contrasting colour. Volume stays a separate per-room encoder knob with
    no numeric display. Updates the panel diagram, control bullets, hardware
    table, simulator caption, and decisions log.
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2026-06-06 Stop on card removal; give play/pause a fixed printed symbol
    Two physical-realism fixes. Lifting the card off the spot now stops
    playback (like taking a record off a turntable), so remove_card stops
    the coordinator and clears the playing state — covered by a new logic
    test. And the play/pause button now shows a single fixed play/pause
    glyph instead of swapping between play and pause icons, because a molded
    physical button can't change its face; playback state is conveyed by the
    button's LED glow instead.
    [core.py]
2026-06-06 Add Denmark-focused bill of materials and GPIO budget
    Gives a concrete shopping list so the user can order parts: quantities
    for the agreed 3-room/no-display design, Danish and EU retailers with
    indicative prices, and a GPIO pin budget showing the ~22 lines fit the
    Pi Zero 2 W's 26 usable pins (no expander needed). Also corrects the
    power spec — the Pi Zero is powered over micro-USB, not USB-C — and
    links the BOM from the README.
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2026-06-06 Document card configuration flow (UID-keyed, content-only)
    The "how do I assign a card after the box is built" question was unanswered.
    Settle it: enroll cards on the box's own NFC spot via the LAN web app, keyed
    by the tag's factory UID, storing only the favorite (rooms/volume stay live
    on the panel so cards remain interchangeable). Records the decision and the
    enrollment flow, and resolves the two related open questions (config
    interface, card->action model).
2026-06-06 Clarify musicbox.local is the Pi address, not today's simulator
    The README implied musicbox.local works now; it doesn't. Spell out that
    it's the finished Pi's mDNS hostname (Avahi gives <hostname>.local free,
    port 80 caveat noted) versus the dev simulator's localhost:8080, so the
    config flow isn't mistaken for something runnable on the laptop today.
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2026-06-06 Rework BOM around a single BerryBase order; accept original Zero W
    The Zero 2 W was out of stock at the DK shop, and pricing/sourcing was
    scattered across five retailers. Consolidate to one BerryBase.de order
    (EU, ships to DK with no customs, ~€55-75 for the whole electronics
    build) with Danish shops as alternates, and accept the in-stock original
    Pi Zero WH for v1 — single-core is ample for the Sonos-controller
    workload and the board swaps out later with no rewiring. Bake in the
    gotchas surfaced while scouting: PSU >=2.5A (not 1A), latching/rastend
    buttons (not momentary), passive piezo, and the PN532 module rather than
    the HAT (which would occupy the GPIO header). README compute row an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
2026-06-06 Lock specific BerryBase SKUs for encoders, latching switches, buttons
    Choosing exact parts after scouting BerryBase: KY-040 encoder w/ breakout
    (panel-mount, onboard pull-ups), the DSQ14 square push-switch for the 7
    latching controls (genuine push-on/push-off that stays pressed in -- the
    metal "vandal" and 24mm arcade buttons only look latching but spring
    back), and the 12mm round momentary for transport. Keeps the whole build
    in one BerryBase order and preserves the no-LED "position is the state"
    design. Records the active-LOW wiring match and the fixed-cap labelling
    implication.
2026-06-06 Lock KY-006 passive buzzer; wire it as a 3-pin module
    Pick the specific piezo: the KY-006 passive buzzer module (EUR1.10),
    which is PWM-drivable for tones -- unlike BerryBase's "Signalgeber" /
    "16 tones" parts, which self-oscillate at one fixed frequency. Update the
    wiring guide's piezo section for the module's S/-/middle pinout. Only the
    PSU and PN532-not-HAT cautions remain open in the BOM callout.
2026-06-06 Make every BOM link a specific product; move tools to BerryBase
    Several lines still pointed at category/homepage/search pages (microSD,
    PSU, hook-up wire, resistor kit) and the tools were generic Kjell links.
    Replace all with specific BerryBase product pages: SanDisk Ultra 32GB,
    the 5V/2.5A micro-USB PSU (resolves the PSU caution by picking the right
    part), the 10-colour 0.14mm wire set, the 525-pc resistor box, and a
    temp-controlled soldering station, lead-free solder, auto stripper, and
    UT131A multimeter. Now the whole build -- tools included -- is one
    BerryBase order, leaving only the PN532 module-not-HAT caution open.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
2026-06-06 Default hook-up wire to a single spool (1-2 colours)
    The 10-colour wire set is overkill for one small box -- a single 10m
    spool has ample length, and most breadboard wiring uses the jumper kit.
    Switch the default to one spool, with a 2nd colour for ground suggested
    as cheap insurance against tracing mistakes; keep the colour set as an
    option.
2026-06-06 Default soldering iron to the goobay AP2 analog station
    The Lötcenter 940 is a solder+desolder combo center -- more than this
    build needs. Switch the default to the goobay AP2 analog temperature-
    controlled station (EUR33): regulated, with a stand, simple. Keep the
    Fixpoint EP5 digital as a step up and the unregulated 4-pc set as a step
    down so the price ladder is explicit.
2026-06-06 Fix solder pricing; offer a small cheap dispenser
    My earlier ~EUR4-8 estimate was wrong: lead-free silver solder is
    pricier (the 0.56mm 100g roll is ~EUR15; larger rolls hit EUR25+). And
    100g is far more than one box needs. Offer the ~EUR3 17g dispenser as
    enough-for-this-build, with the thinner 100g roll as a buy-once, and note
    the price reality so the number isn't a surprise at checkout.
2026-06-06 Use the square momentary button to match the latching switches
    The 12mm round transport button is PCB-mount and small -- it doesn't
    panel-mount cleanly and clashes with the chunky 14x14mm latching
    switches. Switch item 8 to the square momentary (Drucktaster quadratisch
    Schliesser), the momentary twin of the DSQ14: same body, same 12mm panel
    hole, so all 10 panel controls match and wire identically.
2026-06-06 Fix jumper line to Dupont F-M set; add desoldering pump
    The linked 65-cable jumper kit is solid-core male-male only, but the Pi
    Zero's header is male -- connecting it to the breadboard needs female-to-
    male Dupont wires. Point item 11 at the 40-pin F-F/M-M/F-M set so the Pi
    can actually be wired during prototyping, and add an optional desoldering
    pump for fixing beginner solder mistakes.
2026-06-06 Recommend 16GB A1 microSD; fix wrong price
    Pi OS Lite needs ~4GB, so the 32GB card is overkill and its EUR15.60 was
    also mislabelled as EUR6-9. Recommend a 16GB A1 card (A1 matters for a
    responsive Pi; capacity doesn't), note reusing an owned card, and keep
    the 32GB as a still-valid option.
2026-06-07 Scope power (open #8): wall for v1, read-only root FS, AA battery path
    The box stores almost no state of its own (just cards.json, written rarely),
    so the real ungraceful-shutdown risk is OS/SD-card corruption from background
    writes — not app data. A read-only root (overlay FS) removes that risk for both
    the wall build and any future battery, so it's adopted unconditionally and
    cards.json moves to atomic saves.
    Battery is recorded as an optional portability mode, and the chosen chemistry is
    rechargeable AA (NiMH) over LiPo: no lithium in a printed enclosure, hot-swap
    spares, and all parts stock at BerryBase. Documents the accepted trade-offs
    (swap-to-recharge, no fuel gauge → low-batter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
2026-06-07 Add optional AA-battery parts to the BOM
    Gives the README's chosen battery path a concrete, BerryBase-sourced shopping
    list so it can be ordered without re-researching. Every link was verified
    against live BerryBase pages.
    Flags the one non-obvious gotcha: 4 fresh NiMH cells sit ~5.2–5.4V, *above* 5V,
    so the regulator must be a buck-boost (Pololu S13V30F5, fixed 5V across
    2.8–22V), not a plain step-up — otherwise it can't regulate the fresh-cell
    overshoot down. Notes the 3xAA + plain-boost simplification as an alternative.
2026-06-07 Document battery as optional with two paths (AA incl. seamless, PiSugar)
    v1 ships wall-powered and the first build orders no battery, so the earlier
    "chosen: AA" framing overstated the commitment. Reframe battery as a deferred,
    optional portability mode and lay out both viable paths side by side — AA
    (with the TPS2113A power-mux add-on for seamless hot-swap) and LiPo/PiSugar 3
    — so whichever is picked later is already specced and sourced. The PiSugar and
    TPS2113A links are non-BerryBase (flagged as such, with EU sources) since
    BerryBase doesn't stock them.
2026-06-14 Add first GPIO bring-up spike (button → buzzer)
    Now that the hardware has arrived, this is the on-Pi equivalent of
    spike_sonos.py: the smallest end-to-end proof that the Pi can read a GPIO
    input and drive the passive piezo via PWM. Holding the GPIO9 button sounds
    the GPIO18 buzzer — once that works, every other button/encoder is the same
    pattern. Pins match hardware/WIRING.md; uses gpiozero (TonalBuzzer because the
    KY-006 is passive and needs PWM to make a tone).
    [spike_gpio.py]
2026-06-14 Add atomic persistence for the web-editable card and room maps
    The config web app will write cards.json and rooms.json while the box is
    running, so these need atomic saves — the README (open question #8) committed
    to a read-only root FS where a torn write would otherwise corrupt the data.
    Expands config.py with save_card_map/save_room_map (temp file -> fsync ->
    os.replace) and adds the slot->Sonos-room map (rooms.json) the upcoming web UI
    and hardware layer both need. Example-file fallback now only applies to the
    default location, not explicit paths, so on-Pi data files behave predictably.
    [config.py]
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2026-06-14 Add on-device service: GPIO panel + web config over one shared box
    `python -m musicbox.service` is what runs on the Pi: it builds a single
    MusicBox, binds the GPIO panel to it, and serves musicbox.local over the *same*
    box and slot→room dict — so a browser remap or card binding reaches the
    hardware at once, and a PN532 read surfaces in the enrollment page. It degrades
    piece by piece (missing gpiozero/PN532/Sonos) so it also runs web-only on a
    laptop. __main__ doc now points at the service for the device vs the CLI sim.
    [service.py]
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2026-06-18 Arm/disarm cues become rising/falling rings
    The physical arm toggles are momentary — they don't latch down — so the
    switch position can't tell you whether a room is on. Make the buzzer carry
    that state instead: arming plays a rising four-step ring, disarming a falling
    one. The direction is the readout, so you can tell on/off by ear without
    looking at (or feeling) the button.
    Pure change to the shared CUES vocabulary; the GpioBuzzer and console buzzer
    already iterate the patterns, so nothing else changes and laptop/Pi stay in
    sync.
    [feedback.py]
2026-06-18 Play button pauses/resumes instead of restarting the favorite
    The card stays on the spot the whole time it's playing (turntable
    behaviour), and play() keyed off "is a card present?" to decide whether to
    load the favorite. So every play press re-issued play_uri and restarted the
    track from the top — the button could never pause.
    Track whether the current card's favorite has already been started. The first
    play after a card lands loads it; subsequent presses fall through to the same
    pause/resume path the no-card case already used. Lifting the card or dropping
    a new one resets the flag so the next card starts fresh.
    [core.py]
2026-06-18 Coalesce fast encoder turns into fewer Sonos calls
    Each volume detent did a synchronous Sonos read+write round-trip on gpiozero's
    encoder callback thread. Spinning the dial fast queued one slow call per
    detent, so the volume crawled seconds behind the knob and the blocked callback
    thread missed further detents.
    Route encoder turns through a VolumeCoalescer: the detent callback only
    accumulates a pending per-slot delta and returns instantly, while a worker
    thread applies the net delta in one call. A burst that lands while a call is
    in flight collapses into a single follow-up step — we intentionally skip the
    intermediate volume values to stay responsive. on_volume stays synchronous so
    the e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
    [panel.py]
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2026-06-19 Play album/playlist favorites via the queue, not play_uri
    Placing a card bound to an album favorite failed with UPnP 714 "Illegal
    MIME-Type". play_uri issues SetAVTransportURI, which only accepts a directly
    playable stream (a track or radio station). Album/playlist/artist favorites
    are containers, so Sonos rejects their URI outright.
    Branch on the favorite's reference class: containers are loaded into the queue
    (clear -> add -> play_from_queue), streams still go straight to play_uri. As a
    bonus, queue playback is what lets shuffle/repeat span the whole album. The
    container check is defensive — unparseable metadata falls back to play_uri.
    [core.py]
2026-07-26 Add OpenSCAD enclosure model for the single-speaker box
    Shell + faceplate + NFC card, parametric. Fits the 830-point breadboard,
    Pi Zero on printed pegs, PN532 under the card spot, magnet-held card in a
    groove seat. Faceplate and card print face down.
    [musicbox_single.scad]
2026-07-26 Pre-print pass on the enclosure
    Toggle glyph options (power/cast/speaker/room name), buzzer grille relief so
    6 mm of plate doesn't muffle it, blind pocket for the encoder's anti-rotation
    lug, softer Pi snap clips, foot recesses, looser lip fit, taller port slot.
    [musicbox_single.scad]
2026-07-26 Drop the option clutter, trim comments, mount the buzzer
    Power icon only, groove seat only, Pi pegs only; removed dead params and
    print_all. Buzzer can now nests in a pocket behind the grille between two
    fences. Preview dummies use % so they stay out of exported STLs.
    [musicbox_single.scad]
2026-07-26 Use measured part dimensions
    Bushing 7.5 + nut 2 + washer 1.5 -> 3.5 mm plate at the switches; encoder gets
    its own local thickness and a 12.6 relief keying its square base (no lug);
    PN532 span 37.5; measured buzzer, magnet, sticker, screw head; inserts sized
    for the M3x5x5.0 on hand; port slot widened to reach 58 mm along the Pi.
    [musicbox_single.scad]
2026-07-26 One control thickness for both bushing lengths
    Encoder bushing measured 7.0, switches 7.5; 3.0 mm of plate leaves >=4 mm of
    thread for 3.5 mm of nut and washer either way.
    [musicbox_single.scad]
2026-07-26 Raise the box to 54 mm for the 30 mm switches
    Switch backs now sit 15.6 mm above the floor against a 9.5 mm breadboard.
    Added an echo check on that clearance so it can't silently regress.
    [musicbox_single.scad]
2026-07-26 Fix the test coupon, move the buzzer off the card groove
    Coupon now prints in the plate's orientation, gains an insert bore, and its
    groove gauge no longer nicks the membrane relief. Buzzer forward to y=14, 5.9 mm
    clear of the groove instead of 0.1.
    [musicbox_single.scad]
2026-07-26 Shrink the test coupon by half
    94x32 instead of 130x50, tighter margins and a smaller membrane ring. The insert
    bore moved into a boss with the same wall as the shell's posts, and a power icon
    sits in spare margin to check engraving depth at no extra filament.
    [musicbox_single.scad]
2026-07-26 Tighten the encoder relief, drop the groove gauge
    Encoder wiggled at 0.3/side, now 0.15. The gauge slot could never be tested -
    the card's rim is a closed loop - so the seat fit gets checked with a printed
    card instead, adjusted on the card side.
    [musicbox_single.scad]
2026-07-26 Front-mounted switches, drop the pointless NFC relief
    The switches mount bezel-on-top with the nut inside, so the square keying
    recesses become round pockets sized to turn the nut. The membrane relief did
    nothing - PLA is transparent at 13.56 MHz and the PN532 hangs off the
    un-relieved underside regardless - so the plate stays solid at the card spot.
    [musicbox_single.scad]
2026-07-26 Nut 15 mm, add a bezel seat on the top face
    Pocket to ø18.7 for the measured nut. The switches' square bezels now drop into
    a 14.6 x 0.4 seat so they can't sit askew, which also gains 0.4 mm of thread.
    Icons nudged out to clear the seats.
    [musicbox_single.scad]
2026-07-26 Bigger nut pockets, no bezel seats
    Pockets to ø22 for 2.3 mm of plier room round the nut. Bezel seats dropped -
    tightening keys it well enough - so the top face is flat again.
    [musicbox_single.scad]
2026-07-26 Thin the faceplate to 4 mm, drop every control pocket
    The pockets only existed because the plate was thicker than the bushings needed.
    At 4 mm the nuts sit in open air under the plate, the magnet bore becomes 2.8 mm
    so the disc seats against its ceiling, and the plate drops from 125 to 85 cm3.
    Screw heads now stand 1 mm proud on 2 mm of plate.
    [musicbox_single.scad]
2026-07-26 Shorten the bar on the power symbol
    It poked 90% of the circle radius above the ring; now 44%, matching the IEC
    proportions.
    [musicbox_single.scad]
2026-07-26 Encoder hole 8.0 -> 7.1
    Bushing measures 6.8, so 8.0 left 0.6 mm of slop per side and the shaft could
    sit visibly off-centre.
    [musicbox_single.scad]
2026-07-26 Holes to measured bushings: switches 11.8, encoder 7.0
    Bushings measure 11.6 and 6.8, threaded full length, so 0.2 clearance on both.
    [musicbox_single.scad]
2026-07-26 PN532 posts for M3x8, wider pilot
    Posts 3 -> 6 mm so an 8 mm screw engages properly, pilot runs 1 mm into the
    plate so the tip can't bottom out, and 2.5 -> 2.8 because M3 into 2.5 mm of PLA
    takes more torque than a printed post will take. Posts to ø7 for 2.1 mm of wall.
    [musicbox_single.scad]
2026-07-27 Re-read Sonos favorites instead of caching them for the process life
    /api/config now refreshes, so a favorite added in the Sonos app shows up on a
    page reload, and _find_favorite retries once with a refresh on a miss rather
    than error-beeping at a card bound to a new favorite.
    [core.py, server.py]
2026-07-27 Add a printed knob for the encoder
    ø20 x 13 so it clears the volume marks already engraved at 14 mm. Bore keeps the
    shaft's flat so it can't slip, sized for a press fit with no glue, and a recess in
    the underside swallows the encoder's nut. Prints top-face down.
    [musicbox_single.scad]
2026-07-27 Knob: stepped bore for the partial flat, narrower at ø18
    Measured shaft is 15.5 above the plate, ø6, with the flat only over the top
    10 mm, so the bore is round for the first 5.2 and D-shaped above - a full-depth
    D would have jammed 1.5 mm short. Knob height now derives from the shaft so it
    swallows it fully.
    [musicbox_single.scad]
2026-07-27 Half a millimetre of margin before the knob's flat starts
    A slightly longer round stretch on the shaft would jam the knob; losing 0.5 mm
    of flat engagement costs nothing.
    [musicbox_single.scad]
2026-07-27 Knob bore: D-profile straight from the recess floor
    The round step in front of the D was pointless - the recess now clears the
    shaft's round stretch instead, so the flat starts where you can see it and grips
    9.5 mm. Also fixes a variable-ordering bug that had left solid plastic between
    the recess and the bore.
    [musicbox_single.scad]
2026-07-27 Drop the Customizer annotations
    With that panel open it captures these values and renders them instead of the
    file's, which is how a stale knob kept coming back. The part switch stays, it is
    just plain source now.
    [musicbox_single.scad]
2026-07-27 Overlap the knob's bore into its nut recess
    They met at exactly the same z, and coincident faces draw as a membrane in
    preview - so the recess floor looked solid even though the export was fine.
    [musicbox_single.scad]
2026-07-29 Split the CAD into modules, add the label tray
    params/util/icons/shell/faceplate/card/knob/jigs, with musicbox_single.scad as
    the only file to open. Every part renders vertex-for-vertex identical to before
    the split. New part = tray: 60 mm sticker recess inside a card pocket.
    [card.scad, faceplate.scad, icons.scad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]
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2026-07-29 Correct the label grid from the vendor's template
    Measured it: 5 mm gutters, 10 mm left, 20 mm top on A4 - not the centred,
    gutterless layout I had guessed, which would have wasted every sheet. Our output
    now lands on the same lines as their template at 1 px/mm.
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2026-07-29 Label sheets from the config app; drop the faceplate simulator
    New /labels page: pick a Sonos favourite per label and its cover is fetched from
    the speakers, or upload a picture when the art is too small to print well. Sheet
    geometry and PDF writing move to web/labelsheet.py, shared with the CLI.
    The faceplate simulator, its /api/action and /api/state routes and the WebBuzzer
    are gone; /config is now the front page.
    [core.py, labelsheet.py, server.py]
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2026-08-08 Chamfer the card rim so it can't catch labels
    [card.scad, musicbox_single.scad, params.scad]
2026-08-08 Round the card rim over instead of chamfering it
    [card.scad, params.scad, util.scad]
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
